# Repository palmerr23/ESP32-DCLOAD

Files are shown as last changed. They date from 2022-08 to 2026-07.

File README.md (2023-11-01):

# ESP32-DCload
An ESP32-based WiFi controlled DC load

## V3a code is development - not fully tested. Contains battery test, screen rotation and Kelvin sensing 'fix' code.

These files relate to a project published in Silicon Chip magazine in October 2022.  https://www.siliconchip.com.au/ 

Key features:

•	150V and 30A maximum values within a 300W power envelope.

•	Constant voltage (CV) current (CC), power (CP) and resistance (CR)modes

•	Short-circuit, battery and solar cell testing

•	Step test modes (square, ramp and triangle) with variable rise/fall times

•	Data logging

•	Touchscreen control panel 

•	Power off settings memory

•	Remote control via WiFi browser interface

•	SCPI programmable over WiFi and isolated USB

•	Over-voltage, over-current and reverse voltage protection

•	Definition files for the open source SCPI TestController instrument control application (https://lygte-info.dk/project/TestControllerIntro%20UK.html). 

Only compiled code is provided for 2.8" and 3.5" TFT screens (ILI9341 and ILI9488 controllers) as the number of libraries and complexity of code would make it difficult for others to get a clean compile.

The laser templates are designed for a 270mm x 210mm x 140mm blue metal enclosureavailable from eBay, Banggood and AliExpress. The templates have been tested with LightBurn, but should work with other laser cutter software.

The front panel was cut from 2mm acrylic, and the support panel for the CPU coolers from 3mm acrylic. 

The front panel was in the prototype was laser etched with the markings and the holes laser cut. The back of the panel was sprayed matt black. White wood filler was squeegeed into the etched labels and then polished off with very fine DRY sandpaper (> 600 grit). A final coat of clear spray was then appled to seal the wood filler and restore a gloss finish to the acrylic.

Alternately a white markings on black laser print could be mounted behind the clear acrylic panel.

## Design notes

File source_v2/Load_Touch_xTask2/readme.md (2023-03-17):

Additional libraries required:
* Adafruit GFX 
* ArduinoJSON (Benoit BLANCHON)
* ESP32 Wifi (I think all the necessary files are in the basic ESP32 package)
* ESPAsyncWebServer (https://github.com/me-no-dev/ESPAsyncWebServer)

Zip or folders for these have been included. Later versions may also work.
* ESP32 Encoder 
* ESP Rotary
* Button2

Compile with 
* "ESP32 Dev Module"
* Use one of the Partition Schemes with SPIFFS file system and OTA enabled. Minimal SPIFFS (1.9MB APP with OTA/190KB SPIFFS) is recommended.
* Use "Arduino Runs On Core 0" and "Events Run On Core 1". Running both on the same CPU results in lost ADS ADC interrupts.

Known to work with ESP32-WROOM DOWD2. Should work with WROVER as GPIO 16/17 are not required.

Do not use ESP32-S3 DevkitCs as the GPIO to pin number allocations differ.

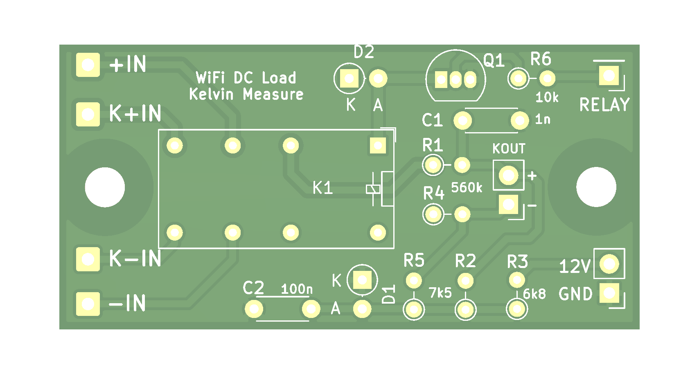
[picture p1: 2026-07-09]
Kelvin board image.png

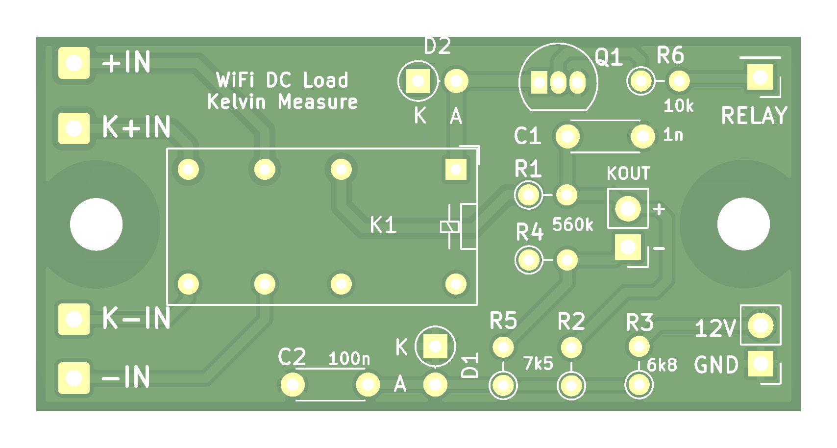
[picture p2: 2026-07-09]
Kelvin-gerber/Kelvin board image.png

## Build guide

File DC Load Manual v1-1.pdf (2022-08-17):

V1.1 – May 2022 | Programmable DC Electronic Load Manual | 1

# WiFi Programmable DC Load Manual

## V1.1 May 2022

This manual describes the features of WiFi Programmable DC Load. It should be read in conjunction with the LCD Controller manual, where some generic features and specifications of the control interface are documented.

## Key Features

- 150V and 30A maximum values within a 300W power envelope.
- Constant voltage (CV) current (CC), power (CP) and resistance (CR)modes
- Short-circuit, battery and solar cell testing
- Step test modes (square, ramp and triangle) with variable rise/fall times
- 10 mA and 10 mV resolution
- Touchscreen Control
- Data logging
- Browser and SCPI programmable over WiFi
- Remembers last five WiFi connections
- Power off settings memory
- Temperature controlled fans
- Over-voltage, over-current and reverse voltage protection
- Modular design allows expansion to higher current loads. Repository: https://github.com/palmerr23/ESP32-DCLOAD

© 2022 Richard Palmer

## Contents

## Safety

Isolated remote control and monitoring via WiFi is the recommended approach for this instrument.
1. Once commissioned, do not make a non-isolated USB connection to the instrument.
- Almost certain damage will occur if the + terminal is connected to GND and a non-isolated USB connection is also made. This connection would create a ground loop of the full output voltage of the supply, as the ESP32’s USB ground is hard wired to the – terminal of the supply.
- Differing ground potentials may also cause damage if the – terminal is connected to GND terminal unless a USB isolator is employed where a mains earth differential is present between the computer and the supply. Both the computer and instrument may be damaged in either case.
2. The load and DUT are NOT PROTECTED under some conditions.
- The load is capable of sinking far in excess (> 100A) of its rated current under some conditions.
- A relay provides some protection for the DUT, but the pulse current may be substantial until this happens.
- The load will sink substantial current if reverse voltage is applied.
While the load is voltage and current protected (relay protected),
the DUT may be damaged by transient currents.
- The load is protected by relay disconnection beyond its maximum input voltage (150V). However, damage may still occur if voltages above this value are applied.
3. The rated voltages and currents of this load are capable of substantial damage, injury or death.
- Never operate the load with the cover removed.
- Ensure that safe work practices are used when the load is used to test high voltages and/or currents.
- Ensure that the load’s current setting is always less than the DUT’s safe maximum
- Undertake DUT short circuit testing with the load’s maximum current setting only a small amount above the DUT short circuit design value.

## Overview

The WiFi Programmable Electronic DC Load offers high performance and flexibility. It has a user-friendly interface, and solid performance specifications, while being withing the capability of the advanced electronics amateur to construct. Its modular construction allows the constructor to select the most appropriate enclosure and panel layouts for their purposes.

Main features:

- Single channel, DC 150V/30A, total power to 300W
- 4 static modes: CV (Constant Voltage), CC (Constant Current), CP (Constant Power) or CR (Constant Resistance) .
- Dynamic (step) mode offering square, triangle and sawtooth operation in CC, CR, CP or CR modes
- Battery characterisation and testing functions
- 3.5” touch TFT, providing a flexible control interface for all settings and readings.
- Kelvin (4-wire) sensing of Device Under Test voltage.
- Built-in WiFi control via SCPI or Web interface.
- Power-off memory function

## Front Panel

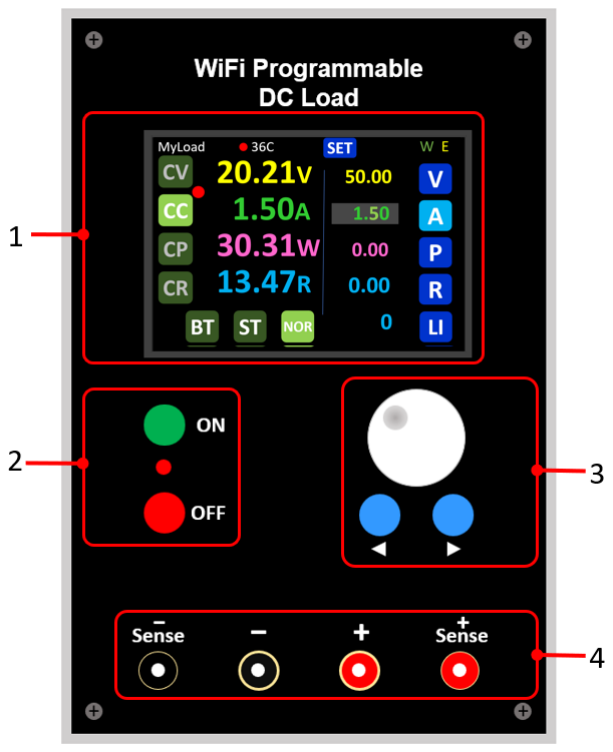
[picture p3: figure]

1. TFT touch control screen
2. On/Off buttons and LED indicator
3. Numeric setting controls
4. Binding posts and Kelvin sensing terminals.

## Operating Modes

## Constant Current (CC)

The electronic load will attempt to sink a current in equal to the set value regardless of the input voltage.

## Constant Voltage (CV)

The load will attempt to sink enough current to control the input voltage to the set value.

The load acts as a shunt voltage regulator when operating in CV mode.

## Constant Power (CP)

The load will attempt to sink constant power in CP mode.

The load current will change linearly proportional to the input voltage to keep sinking a constant power (P = V x I).

## Constant Resistance (CR)

The load attempts to behave like a constant resistance, and changes the current linearly proportional to the input voltage.

## Special Functions

Instructions for using the special function modes are provided in the General Operation section.

## Battery Test (BAT)

The Battery Test function discharges a battery at a known rate until it reaches a defined voltage. At that point the load switches off.

During this process two characteristics are measured:

- | Capacity | Discharge from fully charged to end voltage. Sum the power delivered over time.
- Internal Resistance
| (Equivalent Series Resistance) | Compare the open circuit voltage to the voltage under discharge at a known current.

The characteristics of some common battery types, and appropriate testing values, can be found at the end of this document.

## Step Mode (STEP)

In Step mode, the load can be programmed to switch between two setpoints, or to generate sawtooth or triangular staircases.

The rise and fall time for the steps is also programmable.

## Safe Operating Area and Protection

The device will limit voltage and current in all operational modes and special functions so that it doesn’t operate beyond its maximum voltage, current and power ratings.

When the load is on Off mode, the relay is disengaged. However, the voltage sensing circuitry is still connected in Off mode.

The SOA limiting indicator (1) lights when SOA limiting is in effect.

## Safe Operating Area Protection

The load automatically limits its current when either the maximum power or current is exceeded.

If the applied voltage goes more than a few volts over the allowed maximum, the load will disconnect.

Limiting values are provided in the Specifications table at the end of this document.

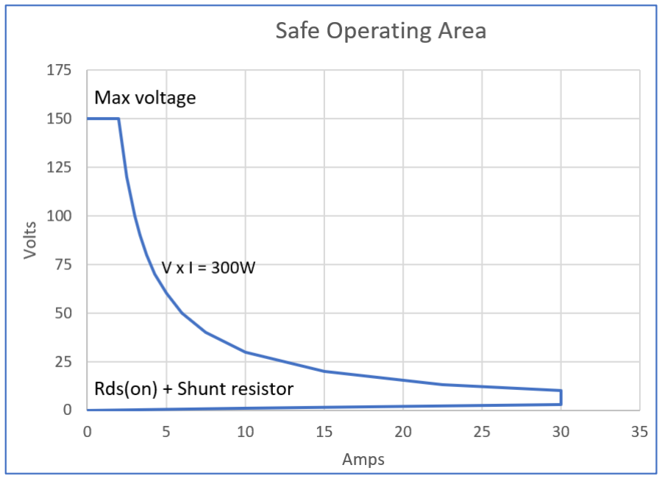
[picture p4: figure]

RDS(on) Limits

- The load has a finite minimum resistance which is a combination of the RDS(on) value of the MOSFETs and the current shunt resistors. The value of the combined minimum resistance is in the Specifications table at the end of this document.

Maximum Power

- The load will reduce the current if the applied voltage and actual load current exceed the maximum power dissipation (P = V * I).
- The SOA limiting indicator will light when this condition occurs.

Overvoltage Protection

- The load will set its target current to zero and disconnect, if a voltage greater than the maximum operating voltage is detected.
When the load is “disconnected” no current will flow, however voltage sensing is still in place.
- While the absolute maximum voltage is well-above the maximum operating voltage, damage will occur to the load if excessive voltage is applied.
- Maximum power limits also apply.

Maximum Current

- It is not possible to set the desired load current greater than the maximum operating value.
- The load will not allow the current to rise above the set value.
- Maximum power limits also apply.

## Reverse Voltage and Current

- The load DOES NOT control current in the reverse direction. If a DUT is connected in a way that provides a reverse voltage, substantially unlimited current will flow until the relay disconnects.
- It is unlikely that the load will be damaged by moderate reverse voltages and currents, however the DUT may be damaged if its current limit is exceeded.

## General Operation

This section describes the basic control functions and front panel operation.

There are some differences when using the web interface, which are described in the Remote Control section.

## On/Off Buttons

The buttons [5] below the LCD screen connect and disconnect the load from the Device Under Test (DUT).

When the load it is disconnected from the DUT, other than the voltage measuring circuit.

The LED [6] between the On and Off buttons indicates the current state of the load, which may also be controlled remotely.

## Screens and Menus

Menu items are selected using the coloured buttons on the touch screen [1, 2, 7 & 8]

For instance, on the main screen there are five buttons V, A, P, R & LI on the right-hand side, which set specific operational values. The buttons change brightness when selected to indicate their status (see Main screen settings, below).

On the left of the screen are buttons to select the main operating modes: CV (Constant Voltage), CC (Constant Current), CP (Constant Power) or CR (Constant Resistance).

Three special function menu buttons BT (Battery Test), ST (Step mode) and NOR (NORmal mode) are arranged across the bottom of the screen.

The SET (SETtings) button, at the centre top of the screen accesses sub-menus to control STep mode, COMmunication parameters, and CALibration functions.

Changing numeric values
Select the item with its associated on-screen button, and use the numeric setting controls [3 & 4] (rotary encoder and buttons) to alter settings. When a setting is selected its background is highlighted, as is one of the digits. The rotary encoder [3] will change the value by 1 unit of the highlighted digit per click. Clockwise rotation increases the value, anti-clockwise decreases it.

Voltage (V) setting selected and the ‘units’ digit being edited.

The highlighted digit is changed by the buttons [4] under the encoder (digit buttons). The left button will move the highlight to a more significant digit, and the right button to a less significant digit.

On/off settings
Touching a selection button for toggle controls [7] (BT, STEP and NOR) will change the value, as will rotating the encoder knob [3] or pressing the numeric setting buttons [4] (right button or clockwise rotation = On, left button or anti-clockwise rotation = Off).

Changing text values
An on-screen keyboard is displayed for test values when the associated selection button is touched. As the individual characters are small, a stylus is recommended to operate the on-screen keyboard.

When a character is touched, it is appended to the end of the string. Backspace deletes the last
character typed.

Shift buttons at the lower right and left change the

case off alphabetic characters and which symbols or numbers are displayed.

The Enter button saves the value and returns to the menu screen.

Processing of the underpinning menu screen is suspended while the on-screen keyboard is active.

## Main Screen

1. Indicators and settings menu button
2. Setting selection buttons
3. Voltage, Current, Power and Resistance value settings
4. Special function buttons
5. Operating mode selection buttons
6. Voltage, Current, Power and Resistance readings

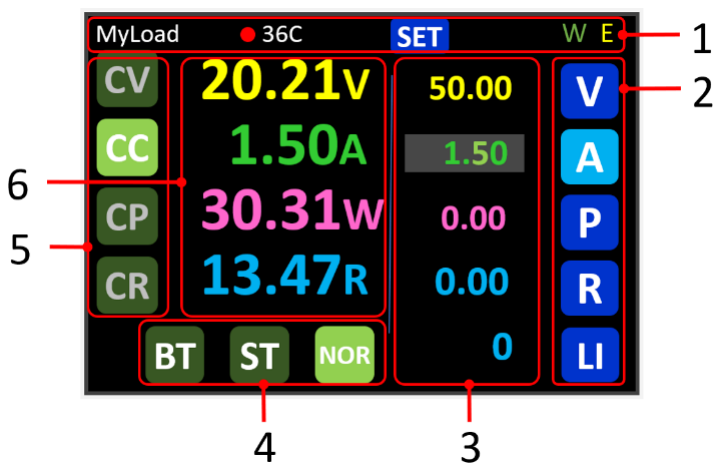
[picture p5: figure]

When values are out of range, the touch screen displays “***”. This most commonly occurs only for the calculated resistance reading, if the calculated value is > 999.99 Ohms
(high voltage and low current).

Top row of screen

- The name assigned to the device is on the left. It can be altered in the Settings > Communications menu.
- Heatsink temperature and fan indicator (no indicator = low speed, green = medium speed, red = full speed).
- The SET button provides access to the STEP, CAL and COM menus.
- Wireless connected (W) and EEPROM save pending (E) indicators on the right.

Main screen settings
Settings are saved automatically to EEPROM approximately thirty seconds after the last value was changed. The [E] indicator is displayed when a save is pending.

Values are not saved more regularly as EEPROM has a limited (~10,000) write cycle lifetime.

Voltage, current, power and resistance target setting
Touch the V, A P or R button on the screen to enable the related control setting.

Use the rotary encoder and buttons, as described in General Operation above, to set the desired output voltage.

Note: The screen settings display updates in real time if values are changed remotely (SCPI or web interface).

Mode setting
Touch the CV (Constant Voltage), CC (Constant Current), CP (Constant Power) or CR (Constant Resistance) buttons to select the desired operating mode.

When switched On, the load will seek an operating point corresponding to the related V, A, P or R setting.

Special Functions
The BT (Battery Test) and ST (STep mode) buttons at the bottom of the screen select these functions.

Pressing a special function button starts the function sequence. The button is red while the function is operating.

When the special function is operating, it can be aborted by touching the NOR button, or by pressing the Off switch on the main control panel.

## Setting the Operating Modes

## Constant Current (CC)

In CC mode, the electronic load will attempt to sink a current in equal to set value regardless of the input voltage.

The load will limit the current to within its Safe Operating Area (SOA) while in this mode.

Operation
1. Set the mode to CC and the desired current in Amps.
2. Connect the DUT and press the On button.
3. Pressing the Off switch will disconnect the load from the DUT.

Short Circuit Testing
Set the target current greater that the DUT’s maximum to test its short circuit capability.

Warning: The DUT may be damaged if the maximum current value is set too high.

## Constant Voltage (CV)

In CV mode, the load will attempt to sink enough current to control the input voltage to the set value. The load acts as a shunt voltage regulator when operating in CV mode.

The load will not sink more than the set current while attempting to reach
the desired voltage.

The load will limit the current to within its Safe Operating Area (SOA) while in this mode.

Operation
1. Set the mode to CV and the desired target voltage.
2. Set the maximum current.
3. Connect the DUT and press the On button.
4. Pressing the Off switch will disconnect the load from the DUT.

## Constant Power (CP)

The load attempts to sink constant power in CP mode.

The load current will change linearly proportional to the input voltage to keep sinking a constant power (P = V x I).

The load will not sink more than the set current while attempting to reach the desired power.

The load will limit the current and voltage to within its Safe Operating Area (SOA) while in this mode.

Operation
1. Set the mode to CP and the desired target power.
2. Set the maximum current.
3. Connect the DUT and press the On button.

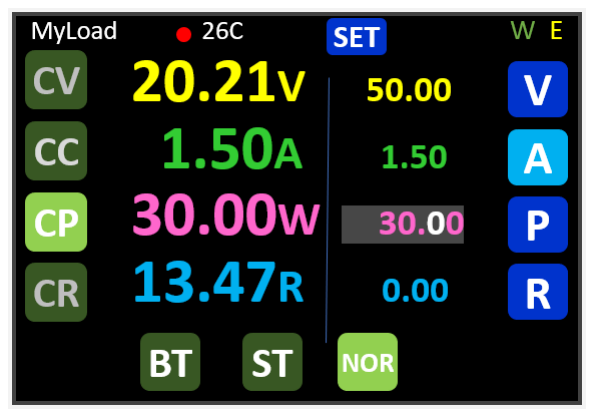
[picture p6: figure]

4. Pressing the Off switch will disconnect the load from the DUT.

## Constant Resistance (CR)

In CR mode, the load behaves like a constant resistance, and changes the current proportional to the input voltage.

The load will not sink more than the set current while attempting to reach the desired resistance.

The load will limit the current and voltage to within its Safe Operating Area (SOA) while in this mode.

Operation
1. Set the mode to CR and the desired load resistance.
2. Set the maximum current.
3. Connect the DUT and press the On button.

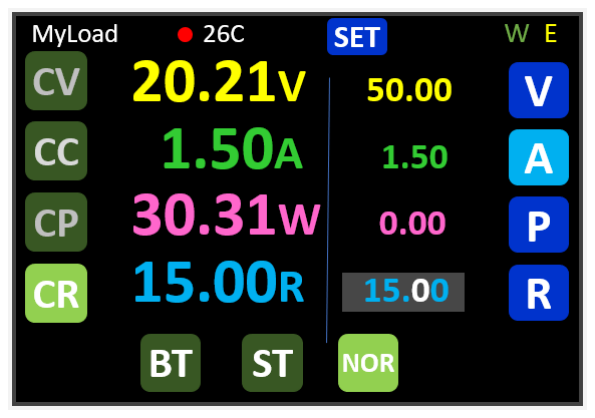
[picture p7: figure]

4. Pressing the Off switch will disconnect the load from the DUT.

## Step Mode

The Step function alternates between two setpoints and may operate in CC, CV, CR or CP mode.

It can provide a simple ‘square’ wave, alternating between the two setpoints; sawtooth or triangular staircases with a selectable number of steps.

The main screen V, A, P and R settings are disabled for Step mode, which has its own settings screen, accessed by touching the SET button on the main screen and then the STEP button on the SETTINGS menu.

1. First stage settings
a. Voltage
b. Current
c. Dwell time for each step
d. Number of steps in the staircase (0 = square or triangle wave)
2. Second stage settings (as for first stage)
3. Number of cycles of the S1/S1 sequence
4. Rise/Fall time between steps

Settings

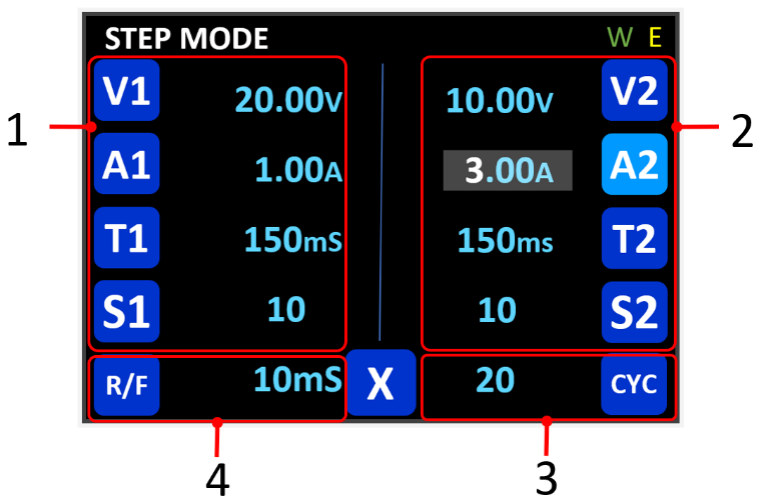
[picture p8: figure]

The operating mode (CC, CV, CR or CP) is selected on the main screen. The mode is combined with the parameters on the STEP settings screen to determine the appropriate operating point at any given moment.

S1 and S2 parameters:

- V&A: The desired voltage (CV mode) or current (CC mode).
For CR and CP modes, the desired value is calculated from P = V * A or R = V / A.
Any parameter for S1 may have a higher or lower value than that of S2.
- T: The time (mS)to dwell at each step of the staircase (triangle/sawtooth) or the time at each setting (square).
The minimum value of T is 5mS, to avoid rapid oscillation between the setpoints.
The dwell time includes any rise/fall time value.
- S: The number of steps between the two setpoints.
Setting both these value to 0 provides a ‘square’ wave, one zero generates a one-way staircase (sawtooth), both non-zero gives an up/down staircase (triangle) output.
CYCles: The number of iterations of the S1 / S2 sequence. Setting the value to zero causes endless repetition.

R/F: Rise and fall time (mS) between stages and steps.
The rise/fall slope is a series of 1mS steps between the two values, rather than a smooth transition.
Setting this value to zero will reduce the rise/fall times to the load’s minimum values (approx. 100uS).
The setting must be less than the dwell times (T1 and T2) for the slewing process to properly complete within each step or stage.

Note: for short rise/fall times(<100mS), particularly when the T1 or T2 parameters are also short (< 100mS), a distorted waveform may be generated, due to the ESP32 task scheduler needing to refresh the screen at regular intervals.

Operation
Step mode limits both current and voltage to the maximum for each step. Main screen modes and values are ignored while stepping.
- For voltage stepping mode operation, set A1 and A2 higher than required for the DUT.
- For current stepping mode, set V1 & V2 higher than the DUT will supply.
- Power and resistance stepping can be accommodated between two specific operating points defined by V1 & A1 and V2 & A2.

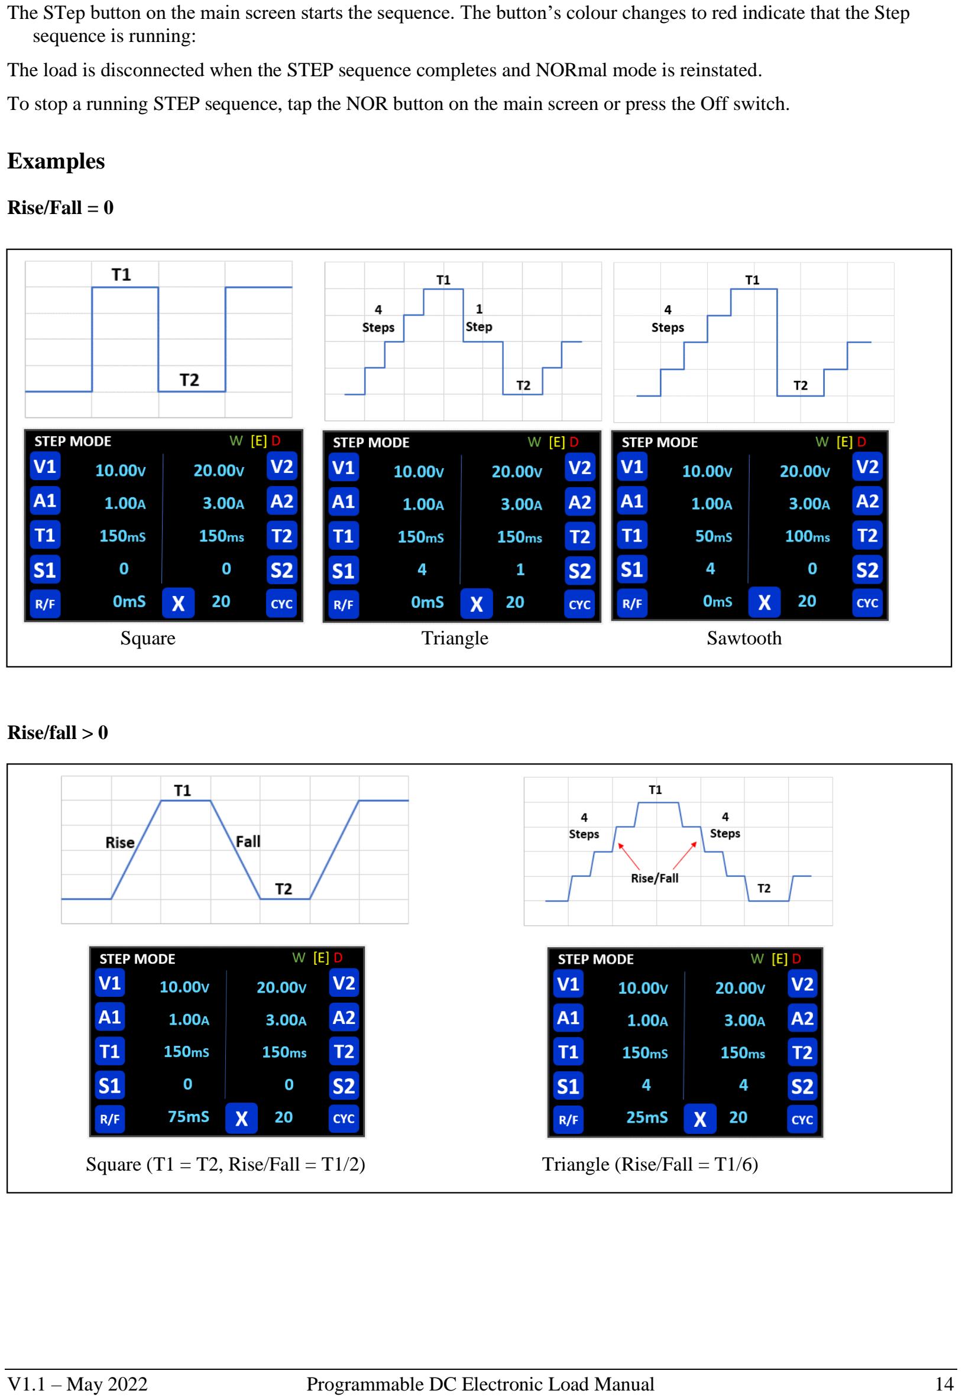
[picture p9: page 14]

The STep button on the main screen starts the sequence. The button’s colour changes to red indicate that the Step sequence is running:

The load is disconnected when the STEP sequence completes and NORmal mode is reinstated.

To stop a running STEP sequence, tap the NOR button on the main screen or press the Off switch.

Examples

Rise/Fall = 0

Rise/fall > 0

Square | Triangle | Sawtooth
Square (T1 = T2, Rise/Fall = T1/2) | Triangle (Rise/Fall = T1/6)

## Battery Testing Mode

While batteries are normally tested in Constant Current mode, CP mode can also be used.

CV mode is not available for battery testing. If it is selected at the start of a test, the mode will automatically switch to Constant Current mode, and the load will change to the Off state.

Settings
1. Battery test final (end of test) voltage
2. Discharge current or power
3. Battery test start button (BT)
4. Battery test cancel button (NOR)
5. Discharge modes (CC, CP or CR only)
6. Live readings
In battery testing mode Logging is always enabled, and a log item is stored every 60 seconds when the internal resistance is measured.

Operation

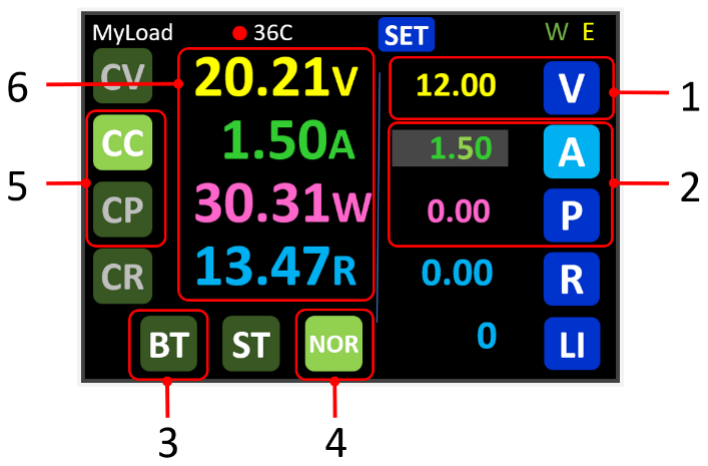
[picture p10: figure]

1. Touch the V button and enter the discharged battery voltage (endpoint for the test).
2. Select the appropriate discharge mode (CC, CR or CP) and enter the desired discharge rate (Amps, Ohms or Power) on the right hand settings.
3. Ensure the output is Off.
4. Connect the battery.
5. Touch the BAT button to initiate testing. The test will continue until the battery voltage reaches the set target voltage.
If the test immediately completes, try starting the test with the load connected (On).
6. During testing, the load will calculate the internal resistance of the battery at the beginning and end of the cycle and every 60 seconds during discharge. The discharge current is set to zero for a few seconds each time, so that the open circuit voltage can be measured.
The battery voltage, current and power being delivered are displayed on the screen while testing proceeds.
7. The test can be aborted at any time by touching the NOR button.
If the Off switch is used to cancel the test, the final values will not be displayed or logged.
8. Once the battery reaches the target discharge voltage, the load will change to the Off state and display the final test results – initial and final internal resistance and battery capacity (AH and mAH).

To stop a running battery test, tap the NOR button on the main screen. The test results, calculated to that point, will be displayed.

The Off switch will also cancel a test, however the final results are not displayed or logged.

At any time, until another test is started, or the load is switched to On, the test logs can be accessed via the web interface (see below).

The ESR and total energy (Watt-hours) discharged values are interleaved with the logged battery voltage readings, as they are calculated.

## Logging

Logging is managed via the main screen Log Interval (LI) setting. The minimum time between log entries is 10mS, and the minimum increment is 10 mS.

A zero (0) value in LI sets logging:

- disabled for NOR mode.
- to SYNC mode for STEP and BAT (see below).
Log values are available via the web interface, and may be queried at any point via SCPI.

The web interface does not need to be live throughout the duration of logging.

Logging results can be called up at any time during the test process or afterward. As the data is held in RAM memory, it is cleared when the load is switched On or the next BAT or STEP operation commenced.

If the maximum number of log measurements (1000) is reached, the earliest values logged are overwritten with newer data.

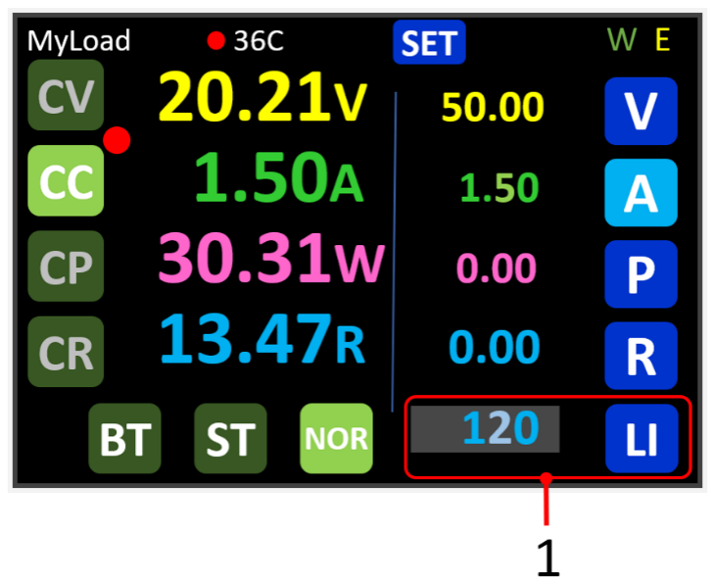
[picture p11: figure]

Operation
1. On the main screen set the LI parameter.
Very small values of Log Interval (<100mS) are not permitted to avoid high processor loads
A zero setting disables logging.
2. Logging data is cleared and logging re-started when any of the following occurs.
- The On button is pressed.
- BT or ST modes are initiated.
3. Log data stops being collected when the output is set Off, either by pressing the Off button, or STEP or BAT mode terminating.
Log data remains available, via the web or SCPI interfaces, until the On button is pressed, or another BAT/STEP cycle is initiated.

The log data format is detailed below.

Step Mode
In step mode, logging begins when Step mode is initiated and ceases when Step mode completes or is aborted.
SYNC mode (LT = 0) | Synchronises log reading with steps and stages. Takes one reading at the end of each step or stage.
FREE mode (LT > 0) | Free-running, logs at fixed intervals, regardless of Step mode settings. Logs each LT period, regardless of step and stage state.

Battery Test Mode
In BT mode, logging begins when BT mode is initiated and ceases when the test completes or is aborted.

Every 60 seconds, discharge is paused and the open circuit voltage measured, so that the battery’s internal resistance can be calculated. The open circuit voltage (OCV) and internal resistance (ESR) are logged.

SYNC mode (LT = 0) | Synchronises log reading with the regular calculation of battery internal resistance. Takes one reading at the end of each step or stage.
FREE mode (LT > 0) | Free-running, logs at fixed intervals, regardless of Step mode settings. Logs each LT period, regardless of step and stage state.

Note: In Battery test mode, the Setting line on the web interface plot includes the setting (CC, CR or CP value), the ESR and Open Circuit Voltage. The CSV log properly identifies all the different values of Setting.

Log Results
Results are available via the web interface or SCPI until the next cycle is initiated (On, BT or ST buttons pressed).

Partial results can be obtained at any point in the logging cycle by pressing the Update button on the Log tab of the web interface. Note that accessing large log datasets during a measurement sequence may cause delays to that sequence.

The data is presented as comma delimited text
(CSV) with a five line heading block and
column headers on row 6.

For each measurement, logging reports:

- Time of measurement is in milliseconds since the start of the test.
- Current reading (A)
- Voltage reading (V)
- Setting (V, A, W, R – as indicated by mode)
- Mode [CV, CC, CP, CR]
- Function [NOR, BAT, STEP]

Battery Test Logs
In Battery test mode, the Setting line on the web interface plot includes the setting (CC, CR or CP value), the ESR and Open Circuit Voltage. The CSV log properly identifies all the different values of Setting.
- Time of measurement is in seconds since the start of
the test.
- At the start of the test, after the load is connected
(On), the battery-is-discharged voltage setting and the discharge current or power setting are logged, depending on the discharge mode selected
- Every 60 seconds, and at the end of the test, the following data is recorded
- Equivalent series resistance (ESR_
- Open circuit voltage (OCV)
- Capacity in AH and mAH (CAP & CAPM)
- The values at the end of the run are recorded after the load has been disconnected.

DC Load Log

Project:

Date:

Operator:

Entries, 26

Time,Voltage,Current,Setting,Mode, Function

0,10.07,0.20,7.00,TERM_V,BAT

0,10.07,0.20,0.20,DIS_A,BAT

62,10.07,0.20,0.20,CC,BAT

63,10.07,0.20,10.58,ESR,BAT

63,10.07,0.20,12.23,OCV,BAT

63,10.07,0.20,0.00,CAP,BAT

63,10.07,0.20,3.42,CAPM,BAT

NOR button pressed or
terminal voltage reached.

70,12.23,0.00,10.52,ESR,BAT

70,12.23,0.00,10.14,CCV,BAT

70,12.23,0.00,0.01,CAP,BAT

70,12.23,0.00,9.33,CAPM,BAT

DC Load Log

Project:

Date:

Operator:

Entries, 3

Time,Voltage,Current,Setting,Mode,Function

0, 12.23, 0.25, 0.25, CC, NOR

50, 10.23, 0.25, 0.25, CC, NOR

100, 12.02, 0.25, 0.25, CC, NOR

Log Data Plot
The Log screen has a plotting function so that the progress of a test can be monitored.

There are two display options:

- The entire log
- The last 10 readings.

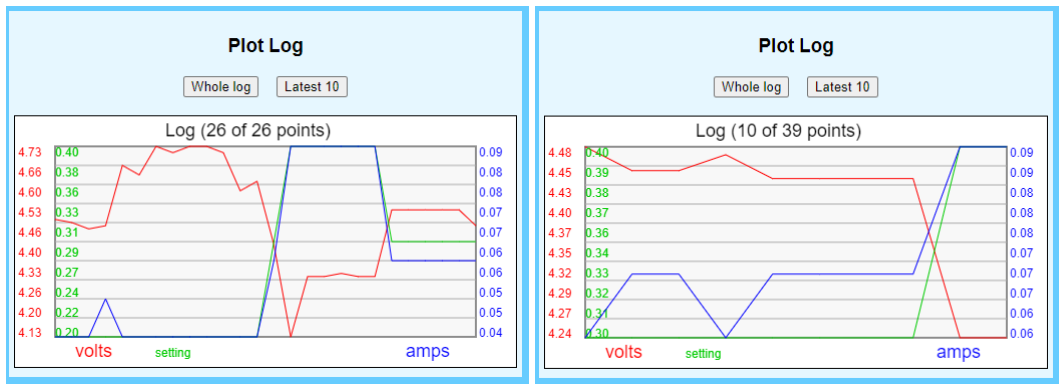
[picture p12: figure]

## Settings Menu

- The Settings menu provides access to three sub-menus:
- STEP: controlling the STEP mode settings
- CAL: voltage, current and screen calibration.
- COM: WiFi and hostname.
Note: Settings are not saved permanently until the [E] indicator at the top right of the screen has gone out (approx. 30 seconds after the last change).

## Step Screen

The operation of this menu is described in the General Operation section, above.

## Calibration Screen

The Calibration screen provides two functions

- Calibrating voltage, current and temperature measurements
- Aligning the touch screen (sub menu)

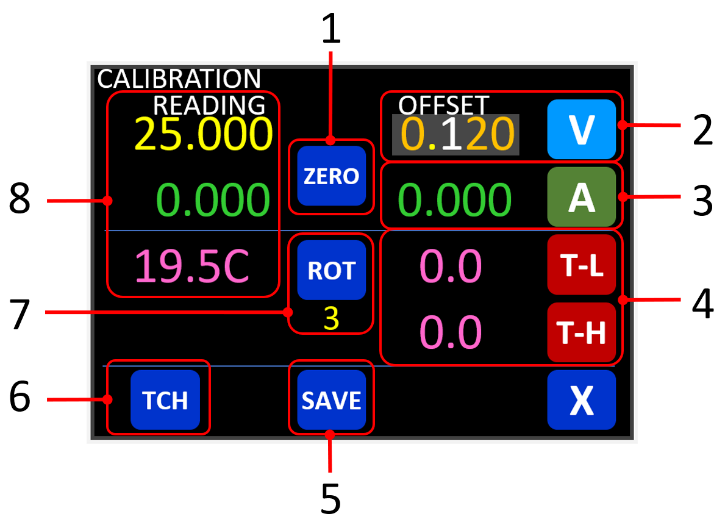
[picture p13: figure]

Voltage, Current and Temperature Calibration

Calibration Screen
1 | Zero current and voltage calibration button
2 | Voltage offset (calibration) button and value
3 | Current offset (calibration) button and value
4 | Temperature low and high offset buttons and values
5 | Voltage, current and temperature calibration update (Save) button
6 | Touch panel calibration menu button
7 | Touch screen rotate button and value
8 | Live voltage, current and temperature readings

High Volts Calibration
1. Connect the Load to a voltage source (preferably higher than 50V DC).
2. Connect a voltmeter across the load.
3. Do not press the load’s On switch.
4. Select CV and set the voltage to a higher value than the test voltage.
5. Navigate to the Calibration menu (SET > CAL).
6. Select the V button and set the voltage OFFSET value to the difference between the voltmeter reading and the value displayed on the left of the screen. If the displayed value is low, the required offset will be positive.
7. Press SAVE.
8. The offset is limited to +/- 5 V to avoid mishaps. If the error is beyond this limit, repeat the process until the correct value is reached.

High Amps Calibration
1. Connect the Load to a current source (preferably higher than 10A).
2. Connect an ammeter in series with the load.
3. Select CC and set the load’s current to the desired test current.
4. Press the load’s On switch.

5. Navigate to the Calibration menu (SET > CAL).
6. Select the A button and set the current OFFSET value to the difference between the ammeter reading and the value displayed on the left of the screen. If the displayed value is low, the required offset will be positive.
7. Press SAVE.
8. The offset is limited to +/- 2 A to avoid mishaps. If the error is beyond this limit, repeat the process until the correct value is reached.

Zero Volts and Amps Calibration
1. Disconnect the Load from any source.
2. Navigate to the Calibration menu (SET > CAL).
3. Touch the ZERO button (the voltage and current zero offsets are automatically calculated).
4. Press SAVE
Zero amps calibration is automatically performed whenever the output is off for more than a few seconds.

Temperature Calibration
A two-point calibration process is used for temperature.
- The LOW value should be close to 20°C (room temperature).
- The HIGH value should be close to the shut-off temperature (65°C).
If a more convenient method is not available, equal volumes of room temperature (20°C) and boiling water will produce a temperature close enough to 60°C for our purposes.
1. Stabilise the thermistor at a suitable low temperature.
2. Input the offset into the T-L setting on the calibration menu.
3. Press SAVE.
4. Repeat the process with a suitable high temperature and the T-H button.

Each calibration setting may be saved separately, or several calibrations made while in the menu, then saved.

All calibration settings are be saved to EEPROM after the E indicator goes out (approx. 30 seconds after the last setting or calibration change).

Touch Screen Alignment

Screen Rotation
Some TFT displays have the touch panel rotated by 180 degrees. If your touch panel does not appear to be responding, tap the main screen diagonally opposite to the SET button. If the SETTINGS menu appears, tap the CAL button in the middle of the screen enter the CALIBRATION menu to rotate the touch settings.

The number under the ROT button will be 1 or 3 depending on the current touch panel rotation.

Touch screen alignment is only required if the
control buttons or on-screen keyboard touch positions are offset from the display.

Touching the screen six times on the + sign at the top left corner of the blue screen, and then 5 times on the + sign at the bottom right corner of the red screen calibrates the touch screen relative to the display panel.

A stylus is recommended for this operation.

## Communications Screen

1 | SSID button and value
2 | WiFi Passphrase button and value
3 | WiFi Auto-connect button
4 | Hostname (instrument name) button and value
5 | IP address reading
6 | Local hostname reading
The Communications screen is entered by touching the
COM button on the main screen, and exited with the X
button.

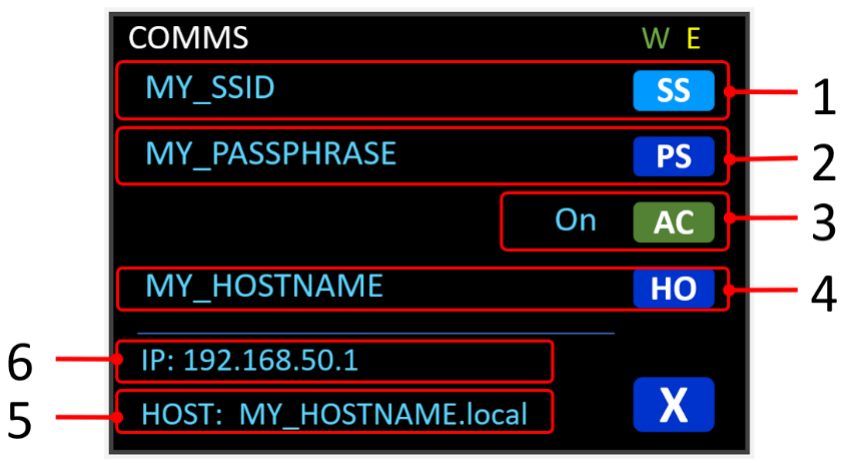
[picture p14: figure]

The load remembers the last five SSIDs entered, replacing the least-recently used if additional credentials are saved.

## Changing settings

Select the appropriate blue button to change the SSID or WiFi passphrase using the on-screen keyboard, as outlined above. Hostname changes will not affect the Web address (HOST:) until the WiFi connection is refreshed (AC Off then On).

To satisfy the requirements of IEEE 802.11 value and are case-sensitive.

- SSIDs may be up to 32 characters in length. While any valid 8-bit value (e.g. special characters) is permitted,
| non-alphabetic and non-numeric values should be used with care.
- Passphrases must be between 8 and 32 characters long (WPA2 enforces an eight character minimum). Any
| legitimate 8-bit value is acceptable.

Changes to Windows 10/11 Bonjour services in 2021 mean that the load can no longer be addressed as hostname.local without Windows registry changes.

## Remote Control

## Web Interface

A simple web interface is provided for the supply. It is accessible from the web address indicated on the COM screen, (on the standard Port 80). Using the example above, the URLs would be:

http://192.168.50.1
or
http:// MY_HOSTNAME.local (not available on some WiFi LANs / operating systems).

Accessing the web interface
The URL for the web screens is found on the SETTINGS > COMMS menu. Either the IP address can be used or the hostname*.

Communication is not encrypted.

* On some WiFi LANs the hostname mode
may not work due to router or operating
system configurations.

Main Tab
The main screen operates in a manner similar to the load’s front panel.

The main difference is that a Settings value [2] is clicked to enable editing.
The selected value has a white background (Watts in the diagram below).

The radio buttons [4] under the scrubber knob [3] determine which unit is changed [e.g. tens, units or decimals).
(Each unit of knob rotation will increment/decrement by one unit in the diagram below).

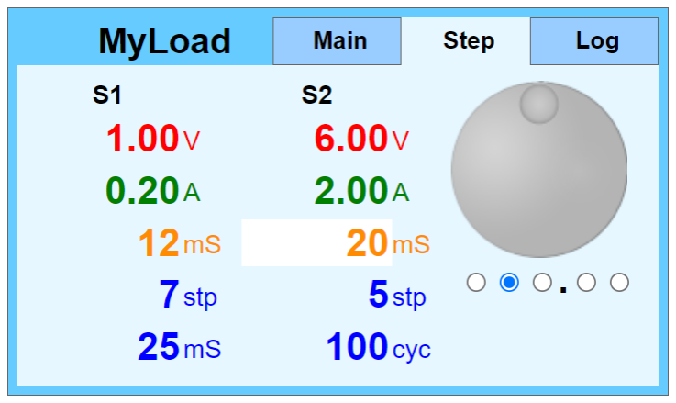
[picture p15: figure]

Step Tab
As for the Main menu, in the Step menu, the are selected for editing by clicking on the value.
(S2 dwell time is selected in the diagram below, and each unit of knob rotation will increment/decrement by ten units).

Log Tab
The Log tab has two functions:

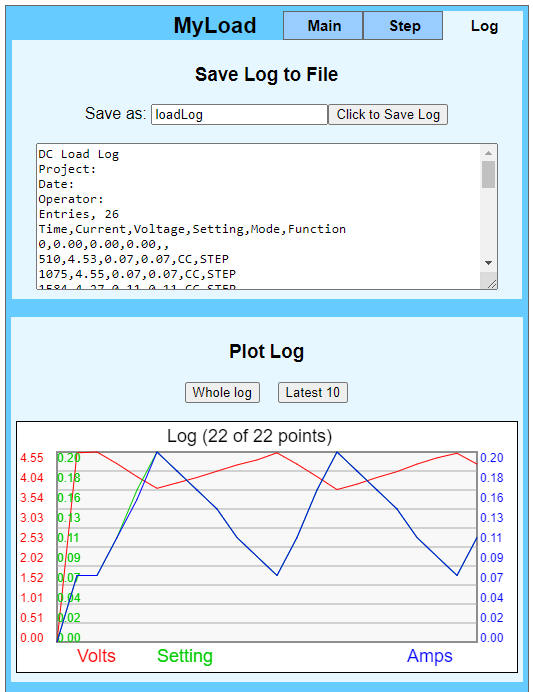
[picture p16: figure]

1. To save Log data to a host computer.
2. to graphically display the current log data, mainly to ensure it is being correctly captured during a test cycle.

Save Log data
1. Enter a file name into the Save as: field.
2. Click the Save Log button.

Data will then be copied into the text box as well as saved to the host computer.

The size of the text box can be altered by dragging the bottom corner of the right-hand
scroll bar

The plotting function auto-scales to the values displayed. The Setting value displayed is that indicated by the function mode (CV, CC, CR or CP).

In the diagram opposite the mode is CC (see log file listing) so the green Setting value plotted is Amps (almost identical to the blue Amps data).

## TestController

Most of the inbuilt functions are controllable from the device Setup in TestController. Calibration is not supported on any of the remote-control interfaces. TestController has its own logging and charting functions.

It is best to avoid changing settings on either the touch screen or the web interface while using TestController, as values are not always updated in TestController if they are changed elsewhere.

Extensive documentation is available at
https://lygte-info.dk/project/TestControllerCommands%20UK.html

The TestController forum is at https://www.eevblog.com/forum/testgear/program-that-can-log-from-many-multimeters/

Configuration
Copy the PlatyLoad.txt device definition file downloaded from the repository into the Devices folder at the location you installed the TestController program.

Copy the PlatyLoadHelp.txt file into you Documents > TestController > Settings folder. Once loaded, as you start to type commands, the Help window below the command line will display the remaining command options.

The setup screen and help information will be available next time TestController is started.

Add the device on the Load Device tab. If DHCP is being used, the DNS name of the device is a better way to identify its Address, as the device’s assigned IP address may change over time.

The Load Devices tab with several devices added. The DNS name for the device or its IP address can be used. Hostnames are not case-sensitive.

Operation
All of TestController’s main functions should operate once the device has been connected.

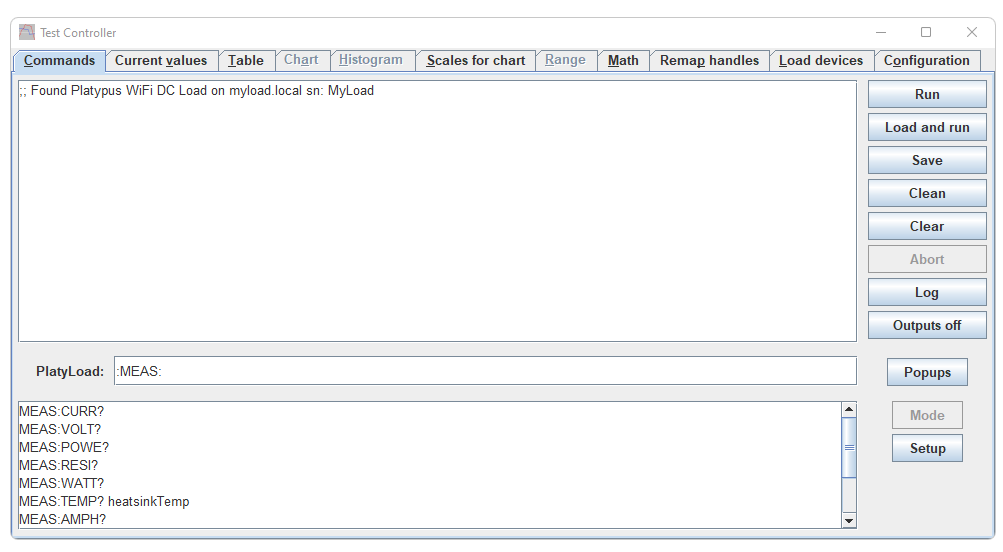
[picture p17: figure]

The main TestController window with the PlatyLoad device selected. There is a partially typed MEASure command in the command line, and the Help widow is displaying the remaining command options.

The Device Setup pop-up window
The Setup pop-up window is opened by clicking on the Setup button on the TestController Command tab, when the Load is selected (Command Line). Most Load settings can be managed from this pop-up, excluding logging and calibration.

The Load’s current settings are loaded into the pop-up when it is opened. They are not updated after that, unless a value is changed using the pop-up’s controls. Therefore, it is not advisable to change settings on either the touch screen or the web interface while using TestController, as the current settings may not be displayed in the pop-up window if they are changed elsewhere.

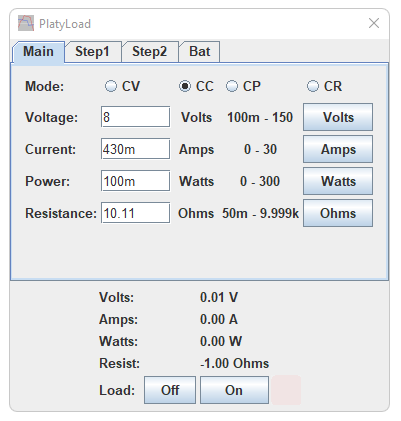
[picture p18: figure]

The Main device pop-up tab. Mode and control values are set in the top section and readings are displayed in the bottom panel.

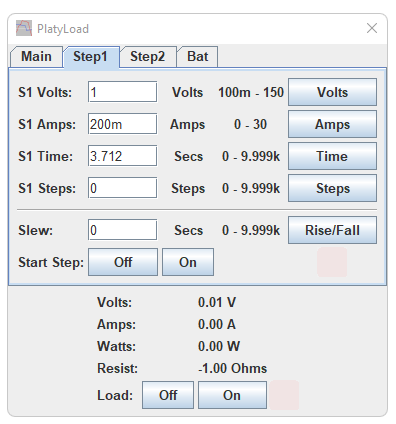
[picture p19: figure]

The Step function screens.

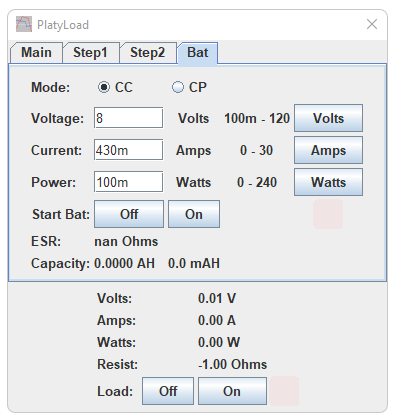
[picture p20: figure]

The Battery testing function screen

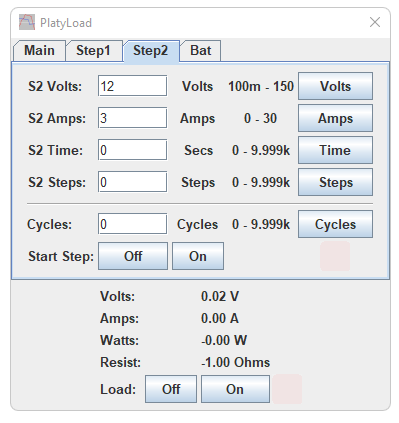
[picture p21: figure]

## SCPI Communication

Standard Commands for Programmable Instruments (SCPI) was developed in the early 1990’s to provide a common syntax and command structure for programmable instruments from power supplies to oscilloscopes and beyond. It was designed as a master-slave protocol, with the controlling software always being master. While it was originally implemented on the GPIB bus (IEEE 488) other protocols, such as serial (including USB serial) and Telnet, are now commonly used.

The IVI Foundation, which is the successor to the non-profit SCPI Consortium, has a website with exhaustive documentation on SCPI and more recently developed, and more flexible instrument communication protocols such as VISA and VXI. https://www.ivifoundation.org/specifications/default.aspx

SCPI commands can be processed from several sources:

- A TELNET connection on Port 5025, for instance from TestController.
- A command packet from a member of the same tracking group as this instrument via UDP packet on Port 8888. (Messages for other tracking groups are read and discarded).
While USB Serial terminal, such as the Arduino Serial Monitor can also be used, significant care needs to be taken to avoid ground loops. (See the safety warning at the beginning of this document). It is highly recommenced that an isolated USB serial connection be used to avoid damage to the computer or instrument. USB Serial commands are equivalent to Telnet.

SCPI Command Format
Commands consist of case-sensitive keywords, separated by colons, and each keyword may have parameters associated with it, e.g. “:SOURce:VOLTage 350 mV” or “:MEASure:VOLTage?”

Commands ending in a question mark are queries, and the instrument should return a value or set of values to any query.

Parameters may be integers, floating point numbers or strings, depending on the command. Numeric commands may be followed by a unit, such as V, mV, A or mA.

Each command, such as “MEASure” can be issued using the full form or by using an abbreviation, which is always the part in upper case, and almost always four characters long. Thus “:MEAS:VOLT?” is equivalent to “:MEASure:VOLTage?”

Some SCPI rules for this instrument:

- Commands are case sensitive. “ABCX” is not equivalent to “aBCX”
- There must be one or more spaces between a command and its argument.
- There may be one or more spaces between an argument and its unit specifier
- String arguments are not enclosed in quotes
- No other spaces are permitted within or between commands. For instance, “:INST:NAME Fred” (no extra spaces) is legal and “: INST : NAME Fred” (extra spaces) is illegal.
- All commands must start with a ‘*’ or a ‘:’, and colons must be inserted between each command in a command line.
- Where unit specifiers are omitted, the natural unit (e.g. Volts, Amps) will be assumed.
- Case is significant in unit specifiers, as the SCPI interpreter recognises a wide range of the possible SI prefixes, e.g. m [milli] and M [mega].
- Floating point number should always have a numeral before a decimal point (leading zero).
- Incorrectly formatted commands will be rejected, and an error message returned, eg.
SCPI_proc: unknown cmd [MY_BAD_CMD]
- Only one command may be issued on each command line.
- Floating point values are stored as single-precision. Thus, 7 significant figure accuracy is available, but not required.
Value are generally returned with four decimal places, however accuracy may be limited to less decimal places. See the instrument Specifications table for value limits and accuracy.
In the detailed explanation of commands below

- Square brackets [ ] indicate the type of input required, e.g. [floating point] or [command]
- Angle brackets < > indicate the specific options available, e.g. <ON|OFF> or <CH1|CH2

SCPI Argument and Return Value Types

Data type | Description
Value | Floating point number. A A leading zero is required for values < 1.0. Actual value set may be constrained by limits embedded in the instrument.
Unit | A one or two character SI value of Amps or Volts (only V, mV, A, mA are recognised).
ON/OFF | String containing the characters {ON | OFF}. Case sensitive.
Group | Integer [1 .. 255]. Group 0 is reserved.
String | Alpha numeric, plus keyboard symbols, no spaces (ASCII 0x21 .. 0x7E). No quote marks. Case sensitive.

## SCPI Command Quick Reference

Command tree | Argument | Function
*IDN? | | | | Identify instrument
*TST? | | | | Self-test (POST) results
:SOURCce
| :VOLTage | | <float[V]> | Set voltage
| :VOLTage? | | | Get set voltage
| :CURRent | | <float[A]> | Set current
| :CURRent?
| :POWEr | | <float[W]> | Set power
| :POWEr?
| :RESIstance | | <float[R]> | Set resistance
| :RESIstance?
| :LOGInterval | | <unsigned integer[S]> | Set log interval
| :LOGInterval?
| :STATe | | <ON|OFF> | output on/off
| :STATe?
:MEASure
| :VOLTage? | | | Measure actual voltage
| :CURRent? | | | Measure actual current
| :POWEr? | | | Measure calculated power
| :RESIstance? | | | Measure calculated resistance
| :TEMP? | | | Measure heatsink temperature
| :LOGData? | | | Current run log data (up to 1000 CSV entries)
:FUNCTION
| :BATTery
| | :STATe | <ON|OFF> | Start/stop Battery test
| | :STATe?
| | :ESR? | | Last calculated ESR value
| | :CAPAcity? | | Last calculated total power discharged
| :STEP
| | :STATe | <ON|OFF> | Start/stop Step mode
| | :STATe?
| | :ACURrent | <float[A]> | S1 current
| | :ACURrent?
| | :BCURrent | <float[A]> | S2 current
| | :BCURrent?
| | :AVOLtage | <float[V]> | S1 voltage
| | :AVOLtage?
| | :BVOLtage | <float[V]> | S2 voltage
| | :BVOLtage?
| | :ATIMe | <unsigned integer[S]> | S1 step time
| | :ATIMe?
| | :BTIMe | <unsigned integer[S]> | S2 step time
| | :BTIMe?
| | :ASTEps | <unsigned integer[S]> | S1 number of steps
| | :ASTEps?
| | :BSTEps | <unsigned integer> | S2 number of steps
| | :BSTEps?
| | :SLEW | <unsigned integer[S]> | Rise/fall time
| | :SLEW?
| | :CYCLes | <unsigned integer> | Number of cycles to repeat
| | :CYCLes?
:SYSTEM
| :ERROR?
| :PASSword | | <text> [8-63 chars] | WiFi password
| :PASSword?
| :SSID | | <text> [2-32 chars] | WiFi SSID
| :SSID?
| :CONNect | | <ON|OFF> | Auto connect to WiFi
| :CONNect?
| :HOSTname | | <text> [2-16 chars] | Network Hostname
| :HOSTname?

## SCPI Command List

*IDN?

Command format | *IDN?
Description | Identify the instrument
Return Info | Manufacturer, product type, instrument name/serial number, software version
Typical return | Platypus,DCL01,myLoad,2

MEASure

Command format | :MEASure:[parameter]?
Description | Query the actual value (reading)

CURRent?

Command format | :MEASure:CURRent?
Description | Measure load current
Return Info | Floating point (Amps)
Typical return | 3.00 (Zero if load is off)

VOLTage?

Command format | :MEASure:VOLTage?
Description | Measure voltage on the output binding posts, or 4-wire (Kelvin) terminals in
Return Info | Floating point (Volts)
Typical return | 12.00

POWEr?

Command format | :MEASure:POWEr?
Description | Return calculated power (volts * amps)
Return Info | Floating point (Watts)
Typical return | 28.5

RESIstance?

Command format | :MEASure: RESIstance?
Description | Return calculated load effective resistance (volts / amps).
Return Info | Floating point (Ohms)
Typical return | 28.5 (-1.00 if out of calculation range)

TEMPerature?

Command format | :MEASure:TEMPerature?
Description | Query the current heatsink temperature
Example | :SOUR:TEMP?
Return Info | Floating point, in degrees C

Typical return 28.5

WAVEdata?

Command format | :MEASure:WAVEdata?
Description | Return
Return Info | Complex, see section “WAVEdata”, below
Typical return | CSV formatted data

SOURce

Command format | :SOURce:[command]
Description | Set or query operational settings, such as voltage, current, or output status

MODE

Command format | :SOURce:MODE [command]
Description | Enable CV, CC, CP or CR mode
Example | :SOUR:MODE CC

MODE?

Command format | :SOURce:MODE?
Description | Query the current mode
Return Info | Text <CV|CC|CP|CR>
Typical return | CC

VOLTage

Command format | :SOURce:VOLTage [float] [unit]
Description | CV Mode: | Set the desired voltage for when the output is ON
BAT function: Set the Battery Test fully-discharged trigger voltage.
Example | Each of these commands will set the target voltage to 2.50V
:SOUR:VOLT 2.50V
:SOUR:VOLT 2500 mV
:SOUR:VOLT 2.50

VOLTage?

Command format | :SOURce:VOLTage?
Description | Query the current target voltage setting
Return Info | Floating point, in Volts.
Typical return | 12.00

CURRent

Command format | :SOURce:CURRent [float] [unit]
Description | All Modes and functions: Set the maximum current that the load will sink when On

Example | Each of these commands will set the target limit current to 2.50A :SOUR:CURR 2.50A :SOUR:CURR 2500 mA :SOUR:CURR 2.50

CURRent?

Command format | :SOURce:CURRent?
Description | Query the target current limit setting
Return Info | Floating point, in Amps
Typical return | 2.00

POWEr

Command format | :SOURce:POWEr [float] [unit]
Description | All Modes and functions: Set the maximum power that the load will sink when On
Example | Each of these commands will set the target limit current to 2.50 Watts :SOUR:POWE 2.50 W :SOUR:POWE 2500 mW :SOUR:POWE 2.50

POWEr?

Command format | :SOURce:POWEr?
Description | Query the target power limit setting
Return Info | Floating point, in Watts
Typical return | 2.00

RESIstance

Command format | :SOURce:RESIstance [float] [unit]
Description | CR mode: Set the target resistance for the load will sink when On
Example | Each of these commands will set the target resistance to 2.50 Ohms :SOUR:RESI 2.50 R :SOUR:RESI 2500 mR :SOUR:RESI 2.50

RESIstance?

Command format | :SOURce:RESIstance?
Description | Query the target resistance setting
Return Info | Floating point, in Ohms
Typical return | 2.00

LOGInterval

Command format | :SOURce:LOGInterval [float] [unit]
Description | Set the time between logged measurements
Example | Each of these commands will set the log interval to 2.50 Seconds :SOUR:LOGI 2.50 S :SOUR:LOGI 2500 mS :SOUR:LOGI 2.50

LOGInterval?

Command format | :SOURce:LOGInterval?
Description | Query the time between logged measurements setting
Return Info | Floating point, in Seconds
Typical return | 2.00

STATe

Command format | :SOURce:STATe <ON|OFF>
Description | Turn the output on or off
Example | :SOURce:STATe ON :SOURce:STATe OFF

STATe?

Command format | :SOURce: STATe?
Description | Query the current status of the output
Return Info | Text <ON|OFF>
Typical return | ON

FUNCtion

Command format | :FUNCtion:[command]
Description | Set or query Battery Test or Step Mode variables

BATTery

Command format | :FUNCtion:BATTery:[command]
Description | Set or query Battery Test variables

STATe

Command format | :FUNCtion:BATTery:STATe [command]
Description | Start or stop the Battery test function.
Example | :FUNCtion:BATTery:STATe ON

STATe?

Command format | :FUNCtion:BATTery:STATe?
Description | Returns Battery Test function status.
Typical return | ON

ESR?

Command format | :FUNCtion:BATTery:ESR?
Description | Return the latest ESR calculation
Return Info | Floating point, in Ohms
Typical return | 8.5

CAPAcity?

Command format | :FUNCtion:BATTery:CAPAcity?
Description | Return the latest battery capacity calculation
Return Info | Floating point, in Amp-Hours
Typical return | 1.5

STEP

Command format | :FUNCtion:STEP:[command]
Description | Set or query STEP mode variables

STATe

Command format | :FUNCtion:STEP:STATe [command]
Description | Start or stop the STEP mode function.
Example | :FUNCtion:STEP:STATe ON

STATe?

Command format | :FUNCtion:STEP:STATe?
Description | Returns STEP mode function status.
Typical return | ON

ACURrent or BCURrent

Command format | :FUNCtion:STEP:ACURrent [command] or :FUNCtion: STEP:BCURrent [command]
Description | STEP Mode: Set the S1 or S2 target current
Example | :FUNCtion:STEP:ACUR 5

ACURrent? or BCURrent?

Command format | :FUNCtion:STEP:ACURrent? or :FUNCtion:STEP:BCURrent?
Description | Returns STEP mode S1 or S2 target current setting (Amps).
Typical return | 4.8

AVOLtage or BVOLtage

Command format | :FUNCtion0 STEP:AVOLtage [command] or :FUNCtion: STEP:BVOLtage [command]
Description | STEP Mode: Set the S1 or S2 target voltage
Example | :FUNCtion:STEP:AVOLT 15

ACURrent? or BCURrent?

Command format | FUNCtion:STEP:AVOLtage? or :FUNCtion: STEP:BVOLtage?
Description | Returns STEP mode S1 or S2 target voltage setting (Volts).
Typical return | 12

ATIMe or BTIMe

Command format :FUNCtion:STEP:ATIMe [command] or :FUNCtion: STEP:BTIMe [command]

Description | STEP Mode: Set the S1 or S2 dwell time. (milliSeconds)
Example | :FUNCtion:STEP:ATIME 0.15

ATIMe? or BTIMe?

Command format | :FUNCtion:STEP:ATIMe [command] or :FUNCtion: STEP:BTIMe [command]
Description | Returns STEP mode S1 or S2 dwell time. (milliSeconds)
Typical return | 1.5

ASTEps or BSTEps

Command format | :FUNCtion:STEP:ASTEps [command] or :FUNCtion: STEP:BSTEps [command]
Description | STEP Mode: Set the number of steps for the S1 or S2 staircase.
Example | :FUNCtion:STEP:ATIME 3

ATIMe? or BTIMe?

Command format | :FUNCtion:STEP:ASTEps? or :FUNCtion: STEP:BSTEps?
Description | Returns the number of steps for the S1 or S2 staircase
Typical return | 3

ACYCles or BCYCles

Command format | :FUNCtion:STEP:ACYCles [command] or :FUNCtion: STEP:BCYCles [command]
Description | STEP Mode: Set the number of complete S1 / S2 cycles before Step mode exits.
Example | :FUNCtion:STEP:ATIME 3

ACYCles? or BCYCles?

Command format | :FUNCtion:STEP:ACYCles? or :FUNCtion: STEP:BCYCles?
Description | Returns the number of complete S1 / S2 cycles before Step mode exits
Typical return | 3

SLEW

Command format | :FUNCtion:STEP:SLEW [command]
Description | STEP Mode: Set the rise / fall time of each step. (milliSeconds)
Example | :FUNCtion:STEP: SLEW 0.015

SLEW?

Command format | :FUNCtion:STEP:SLEW?
Description | Returns the rise / fall time of each step. (milliSeconds)
Typical return | 1.5

SYSTem

Command format | :SYSTem:[command]
Description | Set or query system variables such as hostname and WiFi credentials

ERROR?

Command format | :SYSTem:ERROR?
Description | Return all the error messages currently queued and reset the queue.
Example | :SYST:ERROR?
Typical return | -200,"Command error; Invalid set voltage 3690.00"

SSID

Command format | :SYSTem:SSID [string]
Description | Set the SSID of a preferred WiFi LAN The SSID must be 8 – 32 characters in length to conform with the 802.11 specification.
Example | :SYST:SSID MyHomeWiFi

SSID?

Command format | :SYSTem:SSID?
Description | Returns the SSID of the connected WiFi LAN
Typical return | MyHomeWiFi

PASSphrase

Command format | :SYSTem:PASSphrase [string]
Description | Set the passphrase for the last entered SSID. The argument string is case sensitive. The passphrase must be 8 – 32 characters in length to conform with the 802.11 specification.
Example | :SYST:PASS MYpAssWord23

PASSphrase?
This command is not implemented, as it poses a security vulnerability for the WiFi network.
Command format | :SYSTem:PASSphrase?
Description | Returns a descriptive message.
Typical return | WiFi password can only be SET remotely.

CONNect

Command format | :SYSTem:CONNect <ON|OFF>
Description | Set the instrument to Autoconnect to the WiFi network. Turning this setting OFF effectively disables WiFi
Example | :SYST:AUTO ON

CONNect?

Command format | :SYSTem:CONNect?
Description | Return the autoconnect status
Typical return | 0 (OFF) or 1 (ON)

HOSTname

Command format | :SYSTem:HOSTname [string]
Description | This command sets both the name displayed on the web interface and the hostname component of its URL. The argument string should not be enclosed in quotes. The URL generated is not case sensitive and will be of the form hostname.local The unit may be addressed name as well as its IP address. The hostname will not change until the WiFi server is re-initialised. Restart, or follow this command with :SYST:AUTO OFF then :SYST:AUTO ON to change the web interface URL.
Example | :SYSTem:HOSTname myLoad mDNS will respond to ICMP (ping, DNS) requests to MYLoad.local or myload.local as URLs are case insensitive.

HOSTname?

Command format | :SYSTem:HOSTname?
Description | Return the hostname (same as Instrument name)
Typical return | myLoad

## SCPI Packet Structure

SCPI commands are sent as ASCII text and the command string is NULL terminated in the packet.

Transport (UDP/IP) Headers

Item | Type | Content
IP Header | 20 bytes | Source & Destination Address, Protocol
UDP Header | 8 bytes
Bytes | | Content | Location
2 | | Source Port (optional IPV4, IPV6) | 0-1
2 | | Destination Port | 2-3
2 | | Length | 4-5
2 | | Checksum (optional for IPV4) | 6-7

SCPI packet (follows UDP/IP headers)
Bytes | | Content | Location
4 | char | 'SCPI' | 0-3
4 | uint32_t | Pkt sequence number (0, other than for logging) | 4-7
2 | uint16_t | Message length (max 1024 bytes - to avoid jumbo packets) | 8-9
1 | int8_t | Tracking group (-1 is universal, e.g. all eStop) | 10
16 | char | Sender name or ID? | 11-26
Up to 1024 | char | Content (Always ASCII. SCPI commands and responses. CSV for logging). | 27-1050
1051 | Total | SCPI packet

## Design Overview

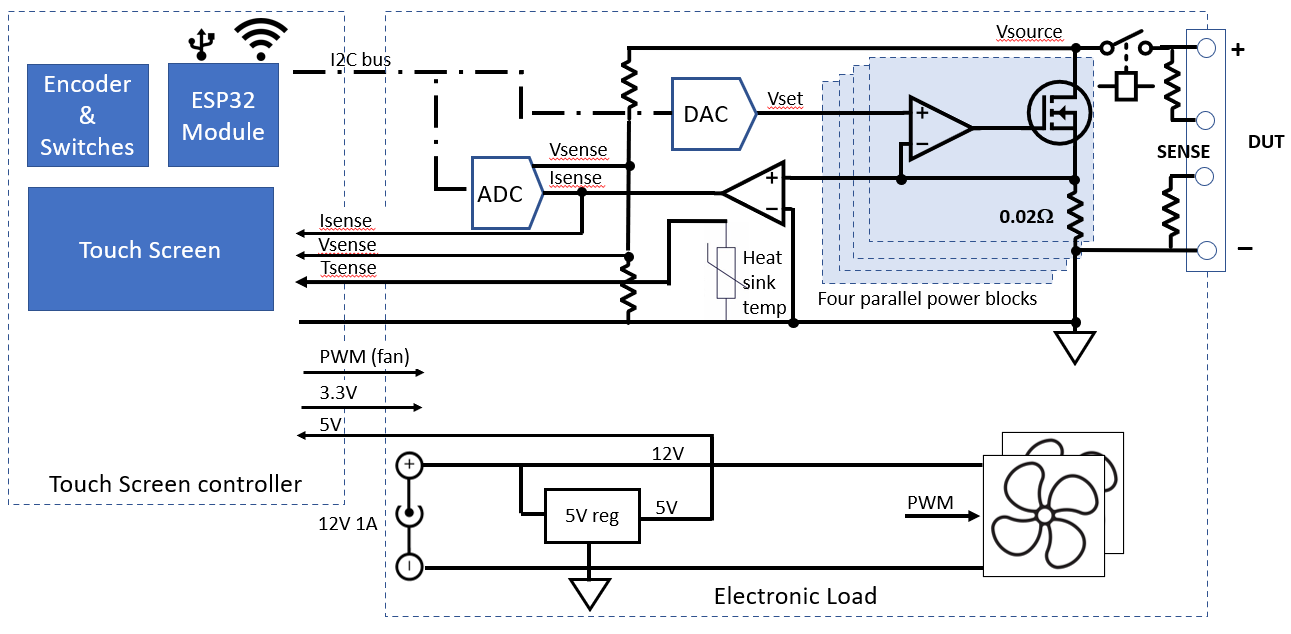
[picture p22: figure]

Fig.2. a simplified block diagram showing the major features of the load. Four identical op amp / MOSFET power blocks are controlled by a DAC. Input voltage and current are measued by an ADC. A relay can disconnect the load. The ESP32 module handles communications and control functions.

At the core of the design (Fig.2) are four power blocks, each with a MOSFET, a shunt resistor and some control circuitry. A control voltage, Vset, is provided to the power blocks by a shared DAC.

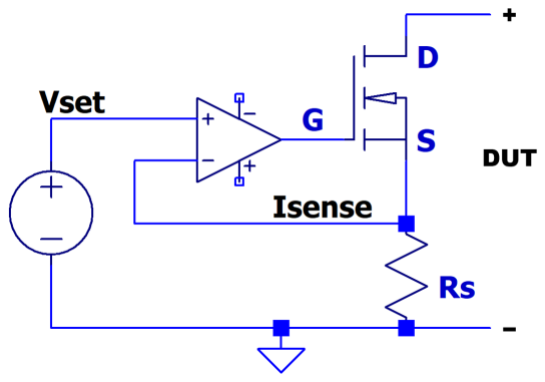
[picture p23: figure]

Fig.3. Basic constant current load circuit. The MOSFET drain current is reasonably proportional to its gate voltage, once the gate threshold voltage has been reached.

The voltages at the load’s input and across Rs are measured by an ADC. The microcontroller iterates Vset until the desired operating conditions are reached.

One of the MOSFET’s case temperatures is read by a thermistor and fed to an ESP32 ADC channel. This value controls both the fan speed, via a PWM signal from the ESP32, and over-temperature shutdown.

Power comes from a 12V plug pack which directly powers the fans and op amps. It is switched down to 5V to power the ESP32 controller and several load components. 3.3V is fed back from the controller to power the DAC and ADC. The general arrangement is the same as for the Hybrid Lab Supply project (SC May-June 2021).

To simplify mounting of the MOSFETs on the CPU coolers and arranging them inside the enclosure, one pair of MOSFETS and their cooler have been separated onto a separate daughter board. Power supply and control signals connect to the main load PCB via a short ribbon cable.

## Schematic

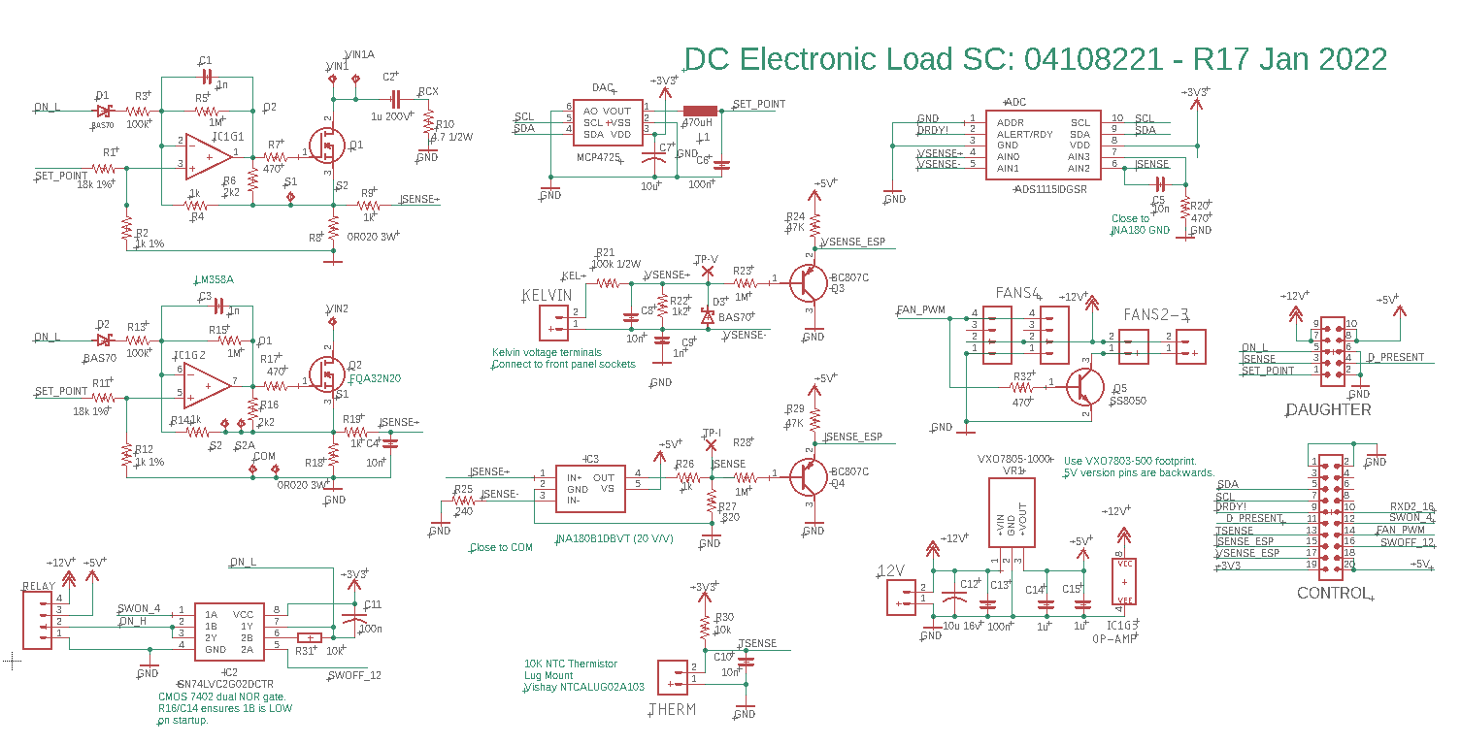
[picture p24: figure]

Fig.15 the main load board includes two power modules, based around IC1, Q1 and Q2; control and monitoring components including the ADC, DAC, IC3, Q3, Q4 and the thermistor TH1. The DAC sets the output current of Q1 & Q2. The input voltage and voltage across the shunt resistors R8 & R12 are amplified by IC2 and measured by the ADC. Current monitor IC2 controls the on/off functions of the MOSFETs and relay. A PWM signal to Q5 sets the fan speed.

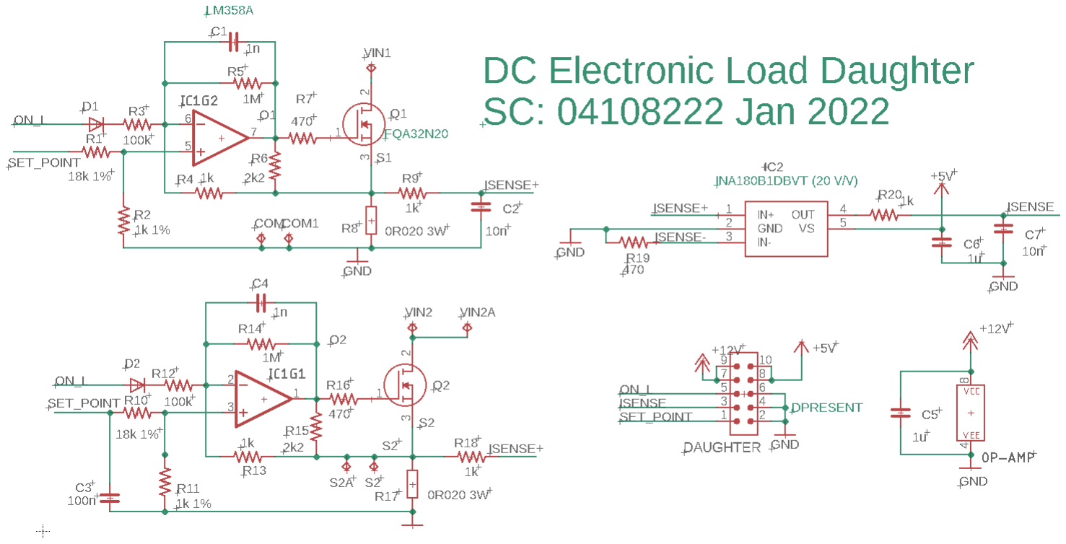
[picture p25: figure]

Fig.16 the daughter board comprises two power modules and a current monitor IC, identical to those on the main board. Control and sensing are transmitted to the main board via the daughter connector.

## Control header pins

ESP32 IO pins are not 5V tolerant. Only 0 – 3.3V signals should be connected to inputs.

GPIO outputs have a 12mA maximum current rating.

Header
Pin
ESP32 Function | GPIO | Header Pin
Function | GPIO
1 | GND | 2 | GND
3 | | 4
5 | SDA | 21 | 6
7 | SCL | 22 | 8
9 | DRDY! | 2 | 10
11 | D_PRESENT | 12 | SW_ON | 4
13 | TSENSE | 14 | FAN_PWM | 26
15 | ISENSE | 16 | SW_OFF | 12
17 | VSENSE | 18 | +5V (Supply)
19 | +3.3V (Return from ESP32) | 20 | +5V (Supply)

A Bill of Materials and construction details are included in the associated Silicon Chip article published in 2022.

## Specifications

Item | Value
Load power dissipation | 300W
Minimum resistance | 0.025 ohms (design)
Input Voltage | Operating: 0 – 150V Absolute maximum: 200V Resolution: 6mV above 100mV Linearity < 1% (above 150mV) when calibrated
Input current | Software limited to max rated dissipation (see Safe Operating Area and Protection) 30A max @ 3 - 10V 2A @ 150V 10A @ 1 V (min resistance) 2A at 200mV (min resistance) Absolute maximum: +/-35A (relay disconnect) Resolution: Set: 7mA Read: 1.5mA 0.2% measurement linearity when calibrated (> 200mA) Warning: Load will sink substantial current if reverse voltage is applied before disconnection (< 100ms).
Constant Current Mode | Set: 10mA – 30A Line regulation < 0.2% (>100mV & 20mA) Rise time (0.1-4A) < 200 uS Limited to max dissipation – see SOA curve
Constant Voltage mode | 50mV min
| Accuracy < 2% above 1V
Constant Power Mode | 0.1W to 300W 1V to 150V input Accuracy < 2% above 1W
Constant Resistance Mode | 0.2Ω to 999.99Ω Accuracy < 2% below 100Ω and above 100mA & 1V
Step Mode | CC, CV, CP, CR modes

THIGH, TLOW 5 mS – 32767 S

Rise/Fall: | zero setting: < as per CC mode
non-zero setting: 1 – 32767 mS

Limited to max dissipation – see SOA curve

Battery Test Mode | CC, CP and CR modes supported
Electronic Protection | Relay current disconnect time < 100mS
Voltage reading remains connected to DUT terminals.
Current | 30A (soft limiting)
35A (disconnects)
Power | 300W (soft limiting)
Voltage | 155V (disconnects)
Reverse Voltage | < -0.1V (disconnects)
MOSFET case temp. | 65ºC (disconnects)
DC input | 12VDC 1.5A double insulated.
Dimensions | 270mm x 210mm x 140mm
Weight | 2 kg

Communication and remote control

Command processing time

Average time for control
change or response after a single command is issued

< 30mS

A single waiting command processed every 20mS.

SCPI commands

Units accepted | Volts and millivolts [V | mV]. No unit specified is equivalent to Volts. Amps and milliamps [A | mA]. No unit specified is equivalent to Amps. Ohms Watts Seconds [S | mS]. No unit specified is equivalent to Seconds.

Remote control connections

WiFi | 802.11 b/g/n/e/i Auto-connect to the SSID/passphrase combinations provided on the COM menu. The five most recently used WiFi credentials are stored, and each is tried until a successful connection is made. Where connection to any of the stored WiFi LANs fails, a local WiFi network is created: SSID: ESPINST PW: ESPPW99X The IP address range provisioned on ESPINST, using DHCP, is 192.168.50.X DHCP IP addresses are used or provisioned in all modes. The current IP address is available on the COM menu screen. DNS name is hostname.local (each instrument implements an mDNS responder) (see SCPI command :INST:NAME and COM menu) Windows computers no longer recognise the hostname.local format. WPS is not supported.
Telnet | Port: 5025 SCPI commands accepted and results returned. Functionality has been tested with the open source software TestController Studio, and an instrument definition file for this software is included in the project’s downloads.
Web (HTTP) | A web interface allows most settings can be altered and most actions initiated. Calibration and Communication settings are not available via the web interface. Port: 80 http://IPaddress The page is and not secured or encrypted.
UDP (packet) | SCPI commands may also be received using UDP packets, although this mechanism is primarily designed for inter-instrument communication. Port: 8888 IP address or hostname as above. Packet specifications are outlined in the SCPI Packet Structure section.
Isolated USB Serial | Damage may occur if a non-isolated USB connection is used. Baud rate: 115,200 SCPI commands accepted and results returned.

## Troubleshooting

Symptom | Likely cause | Remediation
Touch panel not responding. | Touch panel is rotated 180° from LCD. | See the Touch Calibration section.
Touch not centred on buttons. | Touch panel out of register with
LCD.

See the Touch Calibration section.

Voltage or current screen reading
incorrect.
Calibration not completed. | See the Voltage and Current
Calibration sections.

Instruments in a tracking group not tracking.

Voltage &/or Current tracking mode not enabled

See the Tracking Screen section.

Can’t access instrument (Web page or Telnet) remotely. | Wifi not connected. Instrument has joined the ESPINST WiFi network, rather than the WiFi LAN. | See Communication Screen and Specifications – WiFi sections.
Can’t access web interface using hostname. | Duplicate hostname. On some WiFi LANs the hostname mode may not work due to router or operating system configurations. | Use the IP address found in the COMMs console menu.

## Battery Testing Data

The information below is offered as a guide only. Specifications for individual batteries should be obtained from the manufacturer.

Battery
type

Standard discharge
test current*

Nominal
cell
voltage

End of
discharge cell
voltage

Information from

Sealed
Lead Acid

Constant current
(10 hour rate* = 0.1C)
2.1V | 1.75V | Megger. Battery Testing Guide
LiPO | Constant current
(2 hour rate* = 0.5C)
3.6V | 3.0V | https://www.lipoly-battery.com/lipoly- battery-performance-standards/
LiFePO4 | Constant current
(2 hour rate* = 0.5C)
3.2V | 2.5V | https://en.wikipedia.org/wiki/Lithium_iron_p hosphate_battery
NiCd | Constant current
(10 hour rate* = 0.1C)
1.2V | 1.10V | SBS. NiCad Battery Capacity Testing Procedure
NiMH | Constant current
(10 hour rate* = 0.1C)
1.2V | 1.0V | https://m.greenway- battery.com/news/NiMH-Battery-Voltage-- Checking-And-Voltage-Range-964.html

* A common value. Some batteries are rated at a higher or lower discharge rate.
The 10-hour discharge rate (amps) is the amp hour capacity of the battery divided by 10.

### Sealed Lead Acid Battery Characteristics

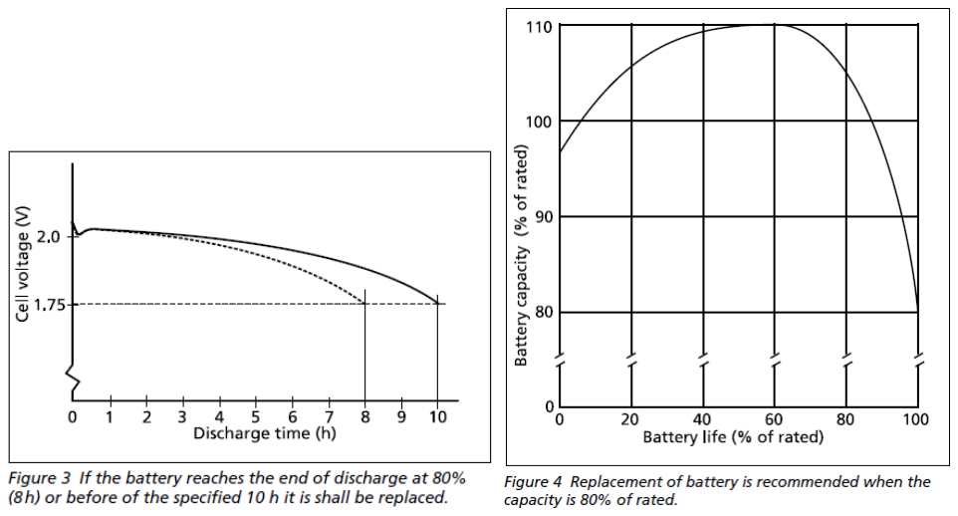
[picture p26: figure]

Diagrams are from the Megger Battery Testing Guide: https://megger.com/products/archive/proactiv/technical/battery-testing-guide

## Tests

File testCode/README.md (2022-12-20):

This code 
* does an I2C scan reporting all devices found
* periodically steps through a range of DAC values, reading and printing the ADS1115 and ESP32 ADC values as it goes

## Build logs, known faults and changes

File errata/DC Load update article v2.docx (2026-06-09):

# WiFi-Controlled Programmable DC Load Update

### Avoid Kelvin sensing until unit is modified

It is strongly recommended that the Kelvin voltage sensing function of the DC load is not used until the modifications outlined in this article have been completed. Normal voltage sensing, via the main + and – terminals is unaffected by this issue.

The WiFi Controlled DC Load project has proved popular, and constructors have suggested a number of worthwhile hardware and software improvements. Two stand out, principally Erwin Bejsta’s improvements to the battery test function, and Ray Miller’s analysis that showed that the original Kelvin voltage sensing arrangements could potentially damage the ADS1115 ADC at high currents. There is no issue if the main + and – terminals are used for voltage sensing.

The hardware changes

- Kelvin sensing issue rectified
- Reduced noise in the 12v supply
- Less control sensitivity to short-term current transients

While the full list of software changes is available in the changelog <link> the highlights are:

- Multiple improvements to battery testing
- Kelvin sensing modes added
- More accurate and rapid control behaviour, particularly in CR, CP and CV modes.
- Improved error condition monitoring (over/under voltage, over current, exceeding AOA).
- Screen rotation now supported as well as touch panel rotation.

Several other constructors have made suggestions that have been included in a software update which is downloadable from <link> and a revised manual is available at <link>.

# Hardware improvements

The main improvement to the hardware resolves the issue with Kelvin voltage sensing. This change is mandatory if Kelvin (4-wire) voltage sensing is to be used.

The other changes require one or two components to be added or changed: improvements to noise on the 12V supply rail to the opamps; a reduction in sensitivity to current transients in ESP32 readings and a reduction to ringing in the DAC output under step changes.

### Kelvin sensing modifications

Some additional circuitry is required to rectify the issue with Kelvin voltage sensing. In the original circuit, the negative Kelvin sensing terminal is connected directly to the negative input of the ADS1115. If Kelvin sensing is being used and there is significant resistance in the lead from the DUT to the main negative input, the negative Kelvin terminal develops a potential below system ground (see Fig.1).

If the load current is 10A, just 0.1 ohms resistance in the negative power lead will create a -1.0V potential at the ADS1115 negative voltage sensing pin and destructive current will flow, as the protection diodes in the ADS1115 are only rated at 10mA.

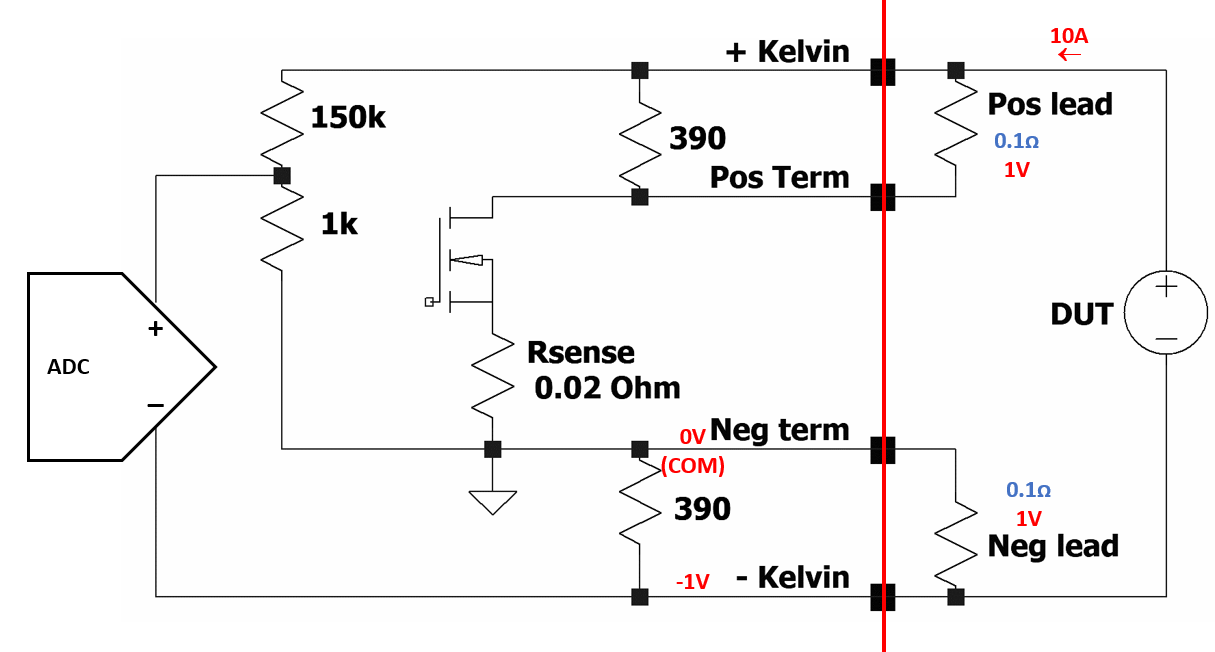
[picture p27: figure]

Fig.1 Simplified circuit of the original DC Load final stage and Kelvin sensing. When substantial current is flowing, any resistance in the negative lead to the DUT will induce a negative voltage directly at the ADC negative input.

To resolve this issue, a voltage divider is inserted into the negative side of the voltage sensing circuit and both positive and negative sides are biased to 0.7V (see Fig.2). This is sufficient to maintain both ADS inputs within acceptable values for normal operations.

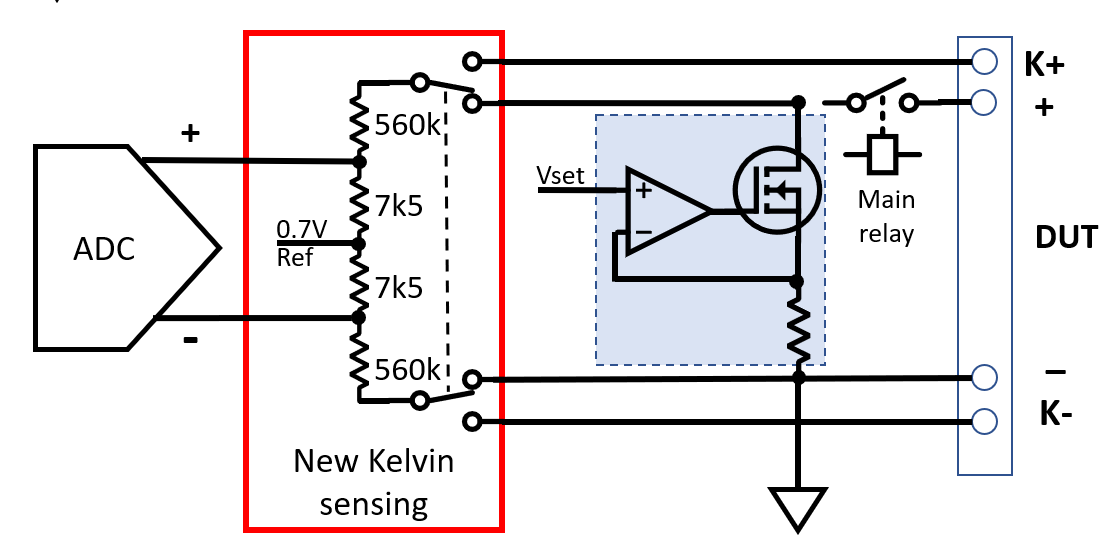
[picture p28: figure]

Fig.2 With a voltage divider in the negative Kelvin sensing leg, with -150V applied directly to the K- input, the current through the voltage divider is around 250uA, well with in the 10mA rating of the ADS1115input protection diodes.

The worst-case fault conditions are when the main negative terminal is disconnected. If the DUT provides 150V, the Kelvin terminal will be at -150V and the divider current is around 0.25 mA, well within spec for the ADS’ internal protection diodes.

A DPDT relay switches between the main and Kelvin voltage sensing terminals, removing any connection between them. The relay is driven by GPIO-16 via transistor Q1.

There are three voltage sensing modes available on the SET menu in the updated code: Main, Kelvin and Auto.

When the load is OFF, voltage is always sensed via the main terminals. With no current flowing, this will be the same value as the Kelvin terminals if they are connected.

When transitioning to ON, a measurement is taken on the Kelvin inputs. In Auto mode, if the voltage is close to the voltage across the main terminals, then Kelvin sensing is used. In Kelvin mode, if an equivalent voltage is not read an error is triggered and the load does not switch on.

The new circuitry in Fig.3 fits on Veroboard, Fig.4, which can be mounted near the relay board in the bottom of the case. There is no capacitor from K- to GND on the circuit as there is already a 1n MLCC in this location on the main Load PCB.

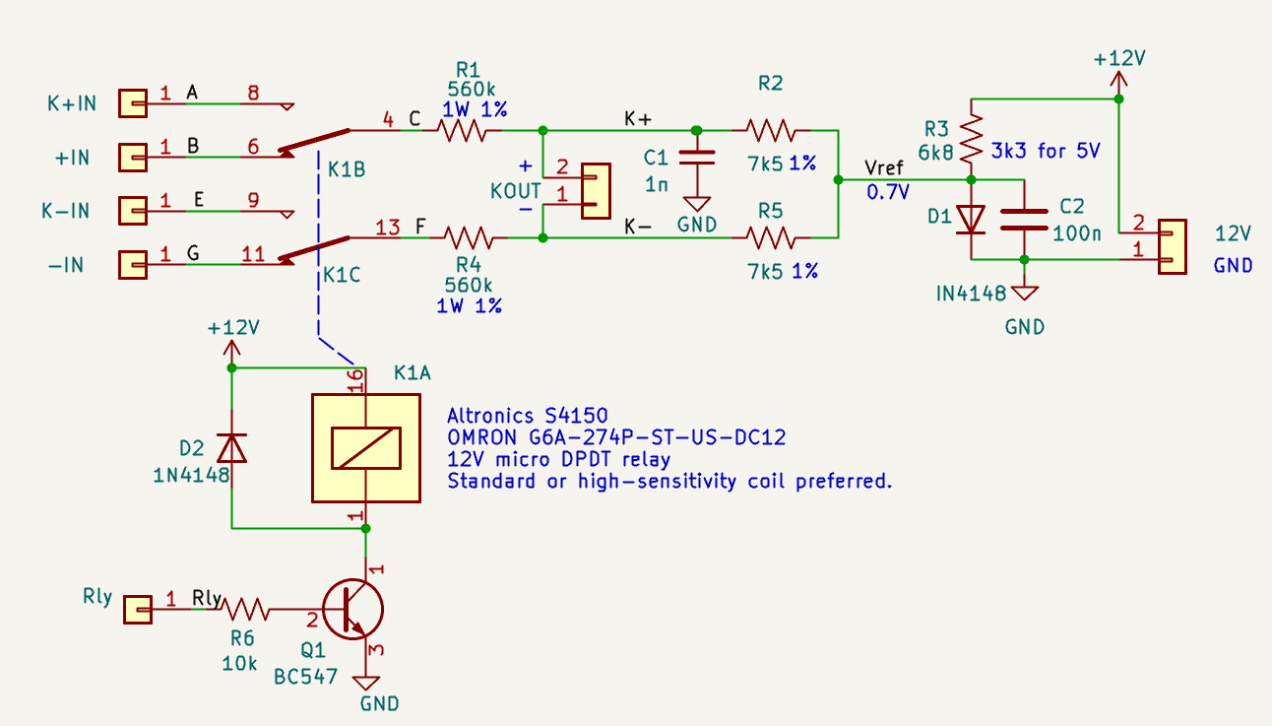
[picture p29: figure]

Fig.3 The components for the small cirucit containing the revised Kelvin sensing input circuitry. Through-hole components have been used to simplify parts sourcing.

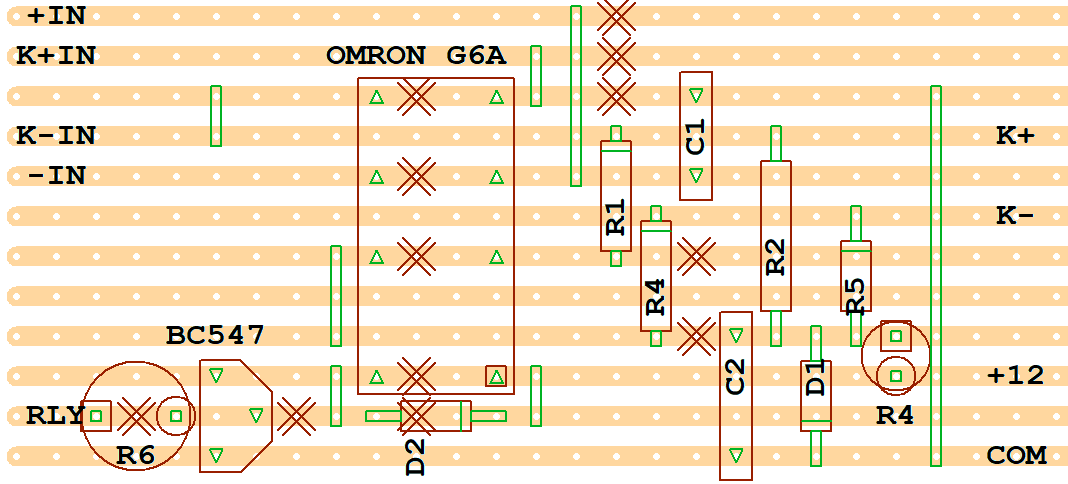
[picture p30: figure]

Fig.4 A Veroboard layout made with VeeCAD. The X marks are cut tracks. Green rectangles are links.

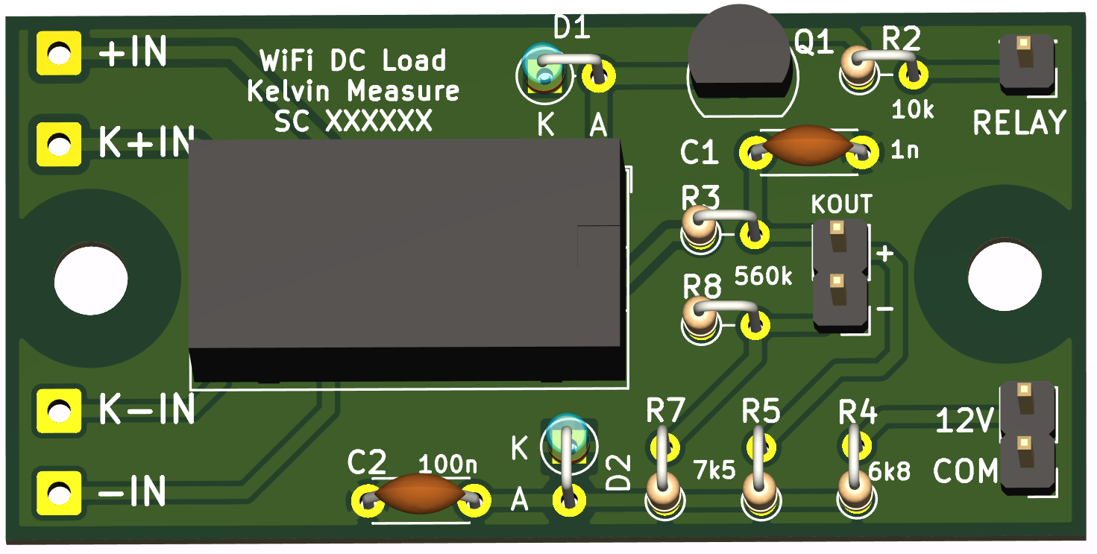
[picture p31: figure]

Fig.4 Alternately, the Gerber files for a 25mm x 51mm PCB are included in the repository.

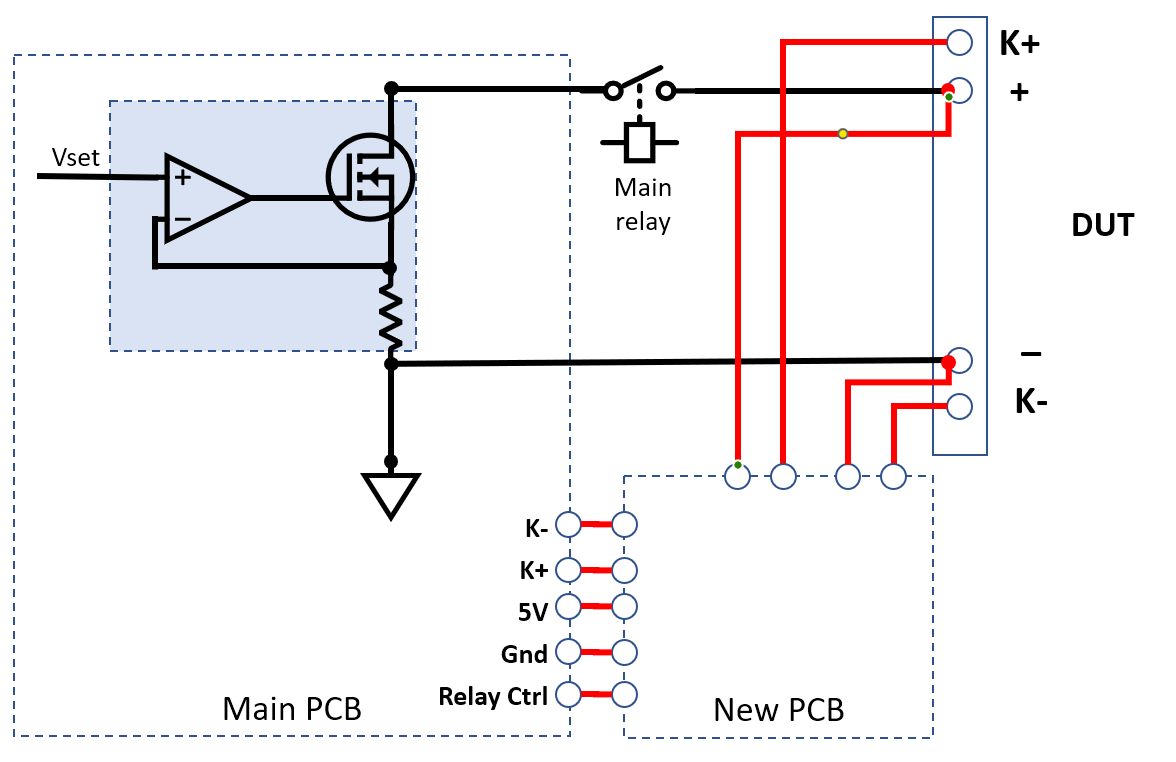
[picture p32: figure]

Fig.5 The new Kelvin sensing arrangements re-route the Kelvin sensing input wires and source additional signals from the main PCB.

### Construction

Through-hole parts have been specified throughout to simplify sourcing.

The DPDT micro relay has an Omron G6V footprint and drop in replacements are available from Altronics and other parts suppliers.

The 560K resistors need to be 1W types for their higher breakdown voltage. These and the 7.5K resistors in the voltage dividers are the only critical values in the circuit.

While we have designed a small PCB for this modification, Veroboard is a viable alternative.

The modifications to the main PCB are straightforward – the 100k ohm resistor in Figs 5 and 6 is bridged and the 1.2k ohm resistor removed. A 330pF capacitor is soldered between the base of Q5 and ground.

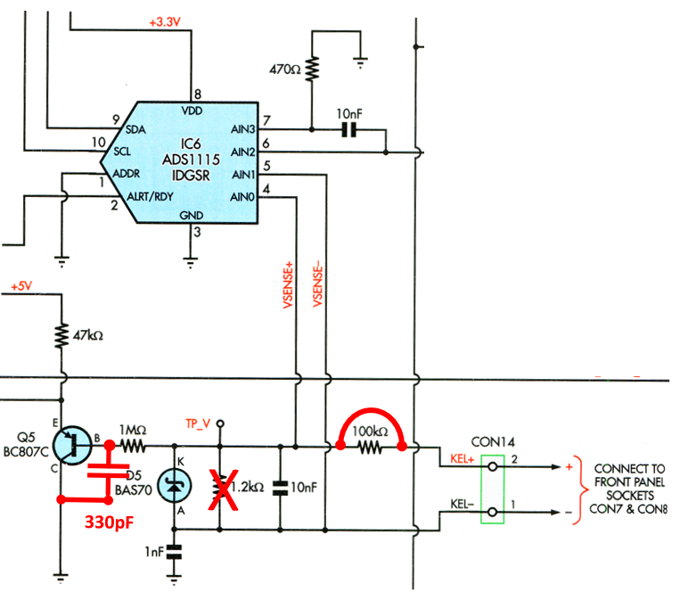
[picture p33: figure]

Fig.5 On the main PCB, one resistor is removed and one is bridged. A 330pF capacitor is added at the base of Q5 to reduce input noise to the ESP32 ADC.

The two existing 100 ohm resistors between the front panel Kelvin sensing and main input terminals are also removed.

While none of the wiring will carry any substantial currents, the + side wires coming from the front panel may be carrying up to 150V, requiring adequate insulation.

The two wires coming from the Kelvin terminals on the front panel are transferred to the new PCB (K+IN and K-IN pads) and the KOUT pads of the new PCB go to the main PCB’s Kelvin terminals.

The four input pads on the left-hand side of the board connect directly to their respective front panel terminals.

The relay signal comes directly from pin 8 of the Control connector, 12V and COM are available on the main PCB. The Relay pins on the main PCB are a convenient source.

After connecting all the cables to the small PCB, mount it in the base of the case, next to the main relay board.

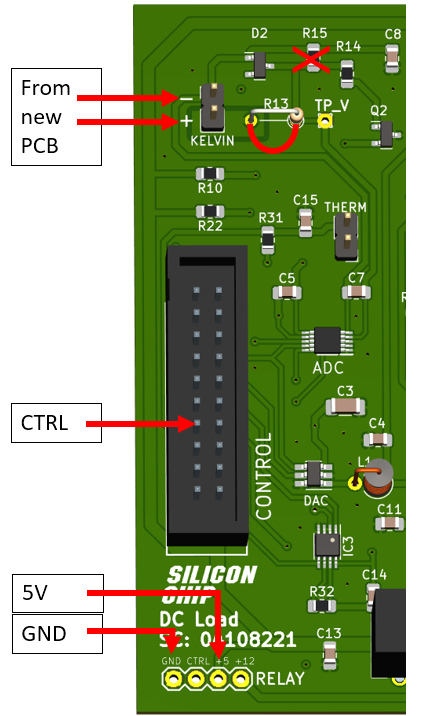
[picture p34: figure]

Fig.7 A visualisation of the main PCB alterations.

### Current transients

Ray Miller detected load current transients, followed by ringing in the current control cycle, that were triggered by false current readings by the ESP32 ADC (see Scope.1). The deviations from the correct value are +/- 30mV indicating a current variation of just over 0.5A.

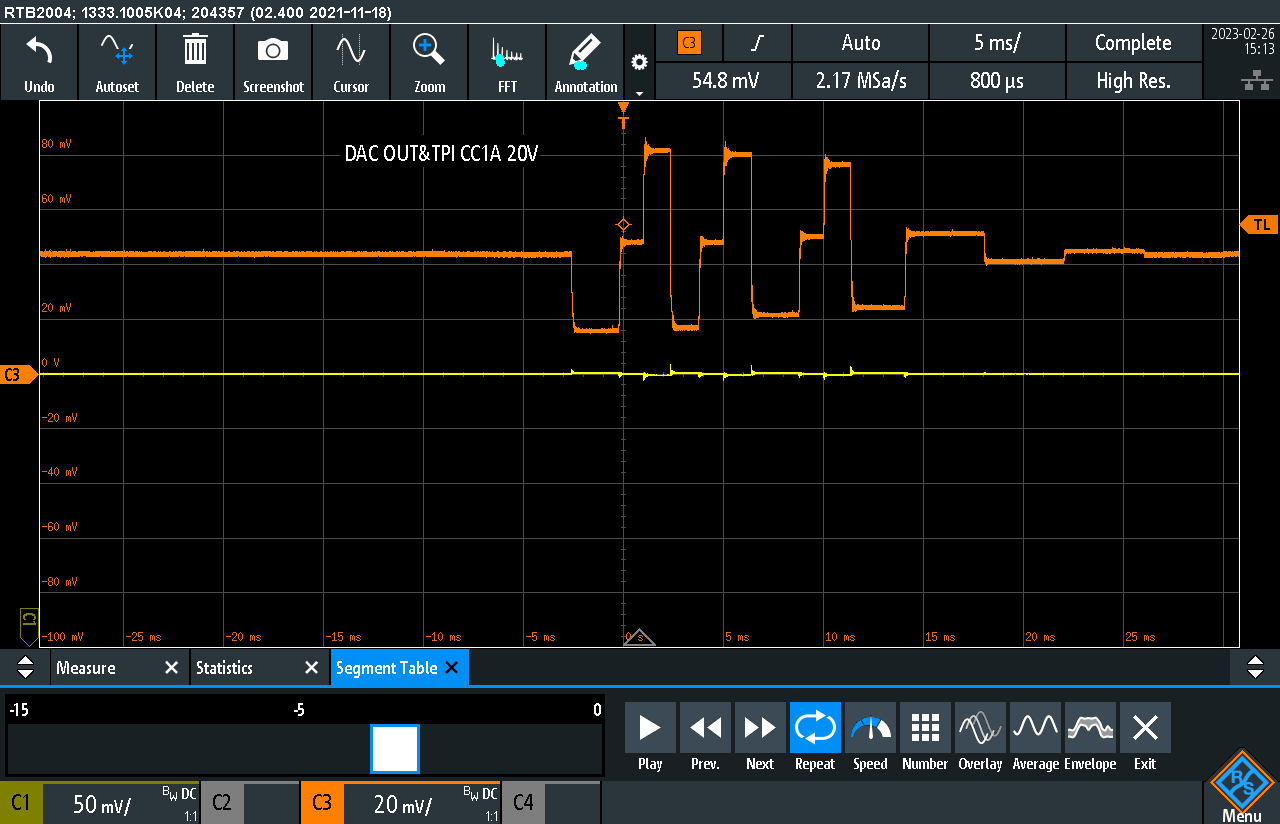
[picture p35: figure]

Scope.1 Ray Miller’s capture of the current waveform resulting from the transient ESP32 current reading. The orange trace is the current at test point TP-I and the yellow trace is the voltage at TP-V. The vertical resolution is 20mV/div and horizontal 5mS/div.

The main ADS1115 ADC completes a set of readings every 2.3mS. In between these cycles the ESP32’s ADC is used to check that there hasn’t been a substantial change to current or voltage that needs immediate attention. In the scope trace, Scope.1, a transient high current reading by the ESP32 ADC, around 3mS before the cursor on the screen, caused a substantial downward change to the DAC current setting, as shown in the top trace. The next ADS sample corrected the issue; however the control loop was not sufficiently damped and it took several control cycles before the output settled.

The issue has been rectified in software: the current difference that will cause an immediate update after a substantially different ESP32 reading has been increased from 0.4A to 5A. While the new value may seem large, instantaneous current control is managed by the op amp driving each MOSFET and the ESP32 ADC readings are mainly intended for more immediate response to short-circuits.

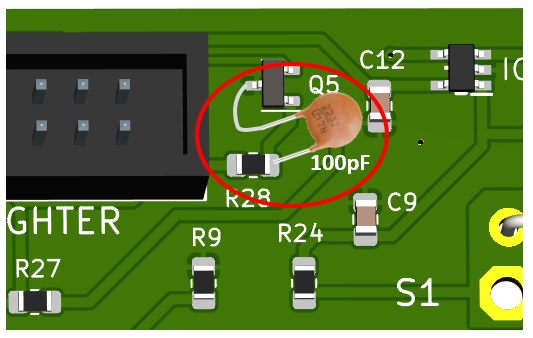
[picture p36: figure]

Fig.6 100pF is added between the base of Q5 and ground on the main PCB to reduce transients in the ESP32 ADC current signal.

To further reduce the sensitivity to transients, Ray Miller’s suggestion of a small (100pF) capacitor from the base of Q5 to ground (see Fig.X) offers a worthwhile improvement.

### Power supply noise

The fans on the CPU coolers produce quite a lot of electrical noise. While there is no observed connection to the load’s performance, decoupling the 12V supply to the op amps from the 12V input could be useful. The12V track (see Fig.X) on the rear of the main PCB is broken and a ferrite bead is inserted into the 12V line. Next to it, add 1uF MLCC from the decoupled track to ground.

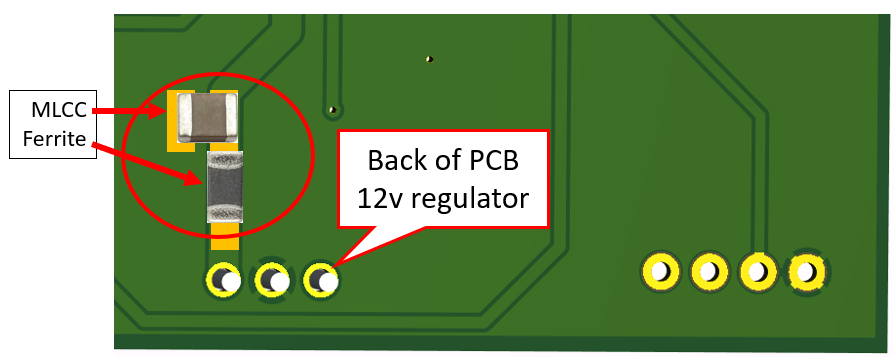
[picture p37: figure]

Fig.x On the underside of the PCB, break the 12V track near the pin of the regulator and insert a ferrite bead across the gap. A 1uF MLCC provides extra filtering of the decoupled supply.

### Opamp output

Another of Ray’s observations was that the input to the opamps exhibited some ringing under step changes (Scope.2) at the resonant frequency of L1 and C4 . Replacing the choke with a 47 ohm resistor rectifies the issue.

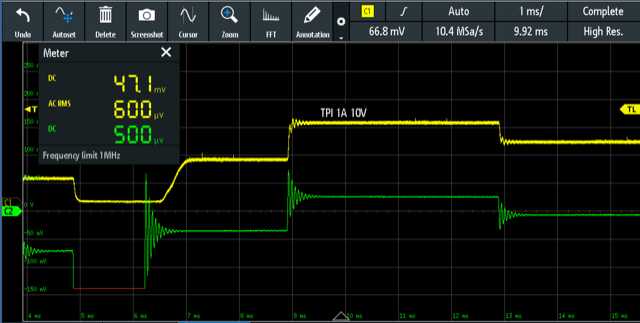
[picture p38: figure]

Scope.2 Ringing at the input to the opamps due to L1 and C4

# Software improvements

### Battery test improvements

There are three main improvements in the battery testing code, none of which require any circuit modifications.

Occasionally the battery test would drop out early due to a single voltage measurement below the test completion setting. Now the code averages several readings before deciding whether the final voltage has been reached.

The screen summarising the results of the battery test previously disappeared after 10 seconds, which was not optimal for unattended testing. Now the summary screen remains visible until the user touches the screen.

The measurement logging rate has been decreased is now able to be set via the logging interval (LI) setting (1 to 999,998 seconds) and the buffer size increased, allowing hundreds of hours of test duration before values start to be overwritten in the circular log buffer.

### Screen rotation

Several constructors noted that their screen displays were upside down, requiring re-compiled code to be provided. An option in the CAL menu is now available for rotating the screen display as well as the touch panel.

## Parts List

1 double-sided PCB coded 1234567, 24 x 42mm

1 micro DPDT relay with 12V coil (Omron G6A-274P-ST-US-DC12 (https://au.mouser.com/ProductDetail/Omron-Electronics/G6A-274P-ST-US-DC12?qs=Rh%252BaoYk36r7iaQnjgsLerg%3D%3D), Altronics S4150)

2 GP silicon diode, 1N4148 or similar

1 NPN GP transistor (CBE), BC4547 or similar

2

### Resistors (All 1/4 W metal film, 5% or better unless noted)

3 7.5k, 1%

1 6.8k

1 10k

2 560k, 1%

### Capacitors (radial ceramic)

1 1 nF

1 100 nF

1 330 pF

### General improvements

The fans create significant electrical noise on the 12V supply and some of the high frequency components of the noise find their way through the op amps to the MOSFET gates. A small, 50-150uH RF choke and 10uF MLCC are inserted into the supply line as shown in Fig.x to isolate the 12V supply to the analogue portions of the circuit.

The choke at the output of the DAC which reduces supply line noise on the control signal also causes some ringing during step changes. It can be substituted by a 100 ohm resistor to eliminate the ringing.

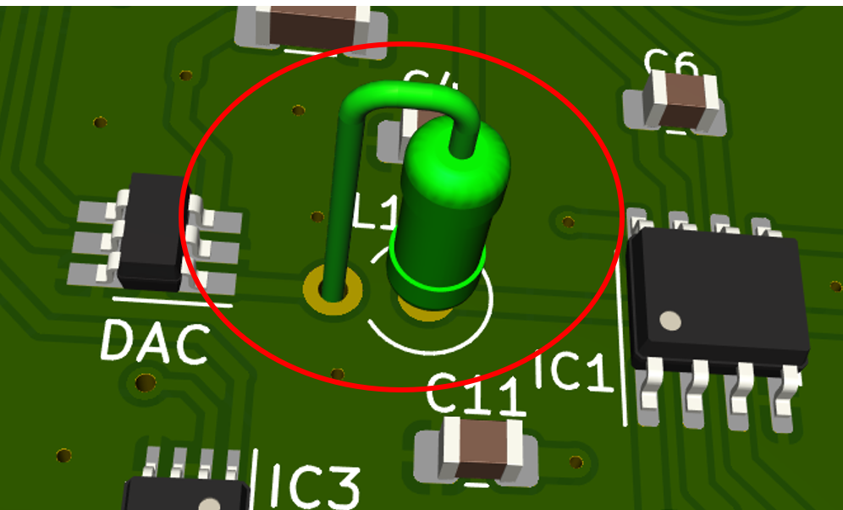
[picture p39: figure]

Fig.x The inductor on the output of the DAC is replaced by a 100 ohm resistor to eliminate ringing during step changes.

Jaycar LF1534

10uF 25V MLCC

100 ohm ¼W resistor

### Open-source code

Several constructors have asked for the code to be made available, so that they can improve or extend it. The original and improved code, as well as compiled binaries, are now available at https://github.com/palmerr23/ESP32-DCLOAD Compiling from source, however, is not for the faint hearted!

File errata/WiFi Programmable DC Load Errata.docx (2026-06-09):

# WiFi Programmable DC Load

# Two issues with initial run of main PCB (SC 04108221)

## 1. Ground via too close to track

A ground via has been paced too close to the SDA track. The via is across from pin 14 on the CONTROL connector and just above the DAC

The issue can be corrected, as in the photo, by carefully disconnecting the top of the via from the track and ground plane with a small (2mm) drill bit.

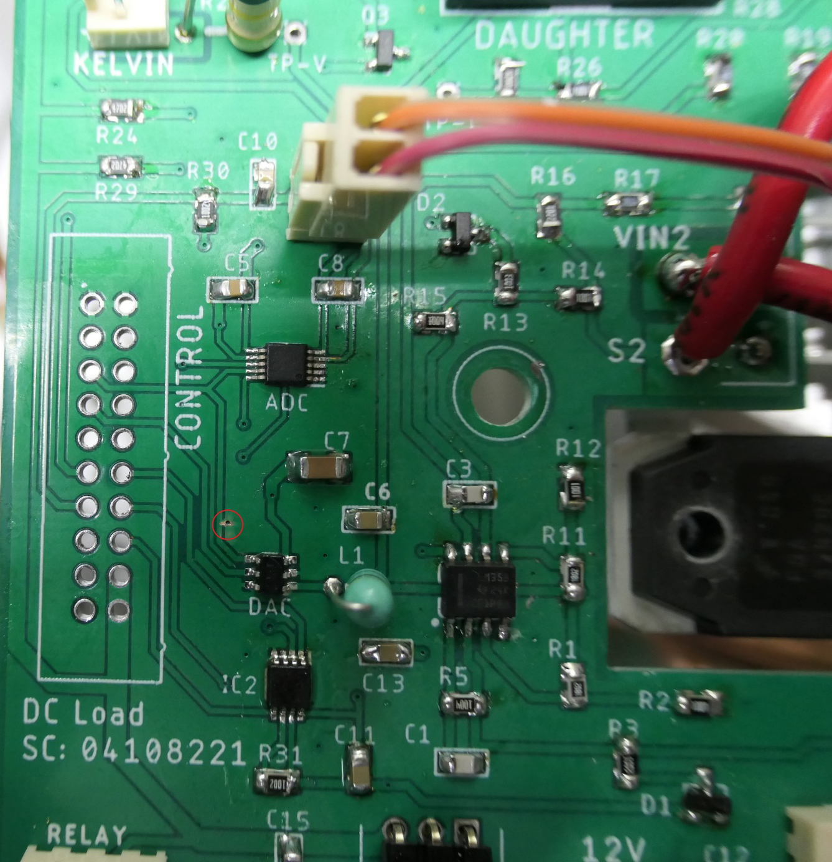
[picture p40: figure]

2

1

## 2. Regulator orientation is incorrect and heatsink may be required

The 7805 regulator pin markings are reversed on the silkscreen overlay. Input Pin 1 should go to the right, connecting to the 12V input terminals.

The prototype used a VXO7805 switching regulator and no heatsink was specified when the parts list was amended to a 7805 regulator. A small flag heatsink may be required. A ‘touch test” will indicate whether a heatsink is required.

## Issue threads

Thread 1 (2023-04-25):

Touch is mirrored in horizonal axis

derwhalfisch, 2023-04-25:
In both touch orientation settings (1 and 3) the touch is not correct. Mode 1 is 'rotated' appropriately but it still mirrored in x/horizontal direction.

palmerr23, 2023-04-25:
I've used many different brands of screen across a number of projects and this is the first time anyone has reported a touch panel that is _mirrored_!

Just to check - is the display the right way up, and displaying correctly (some folks have reported screens that are rotated)?

The firmware is the latest published one, and I'm working on several improvements suggested by constructors.

I can't see an easy fix to a mirrored touch panel, but I'll think on it.

BTW: don't use the Kelvin voltage sensing - there's an issue with it.

derwhalfisch, 2023-04-25:
Hi

I've just flashed your v3 bin on again to check. I have SROT=1, TROT=3 and the touch is mirrored in x-axis.

I found in myLScreenCal.h, line 127 that the tsrot is basically constrained to 1 or 3; 	sc.tsRot = (sc.tsRot + 2 ) % 4;

so I changed this to 	sc.tsRot = (sc.tsRot + 1 ) % 8; hoping that one of the other modes would be useful but I didn't have any luck. It won't draw numbers higher than 4 either (shows "***" instead) so I may not have even been testing all 8 modes.

palmerr23, 2023-04-25:
I wouldn't have expected further _rotations_ of wither the screen or touch pad to fix a _mirroring_ issue.

Also, I don't think there are more than 4 modes available in the XPT2046:

Line 62 in XPT2046_Touchscreen.h
	void setRotation(uint8_t n) { rotation = n % 4; }

It's worth checking that the touch controller is actually an XPT2046. If not, an alternate driver might do the trick.

What I'm thinking is that it might be possible to subtract the read X position from the maximum before checking whether a block is touched in  myLtouchprocess.h after line 217
p = ts.getPoint();
#ifdef MIRROR_TOUCH
p.x = 4096 - p.x; // might need to be sc.thmax rather than 4096, as my screen edge is at 3900 counts
#endif

derwhalfisch, 2023-04-25:
I probably misinterpreted another discussion I found of the XPT2046 in which they were discussing 3 bits that described the orientation, and in which there was a reflection issue also.

I do need the screen rotation capacity of the latest firmware but I'll see if i can try your suggestion here in the v2 codebase.

Thanks for the help, I'll come back with the result.

derwhalfisch, 2023-04-25:
I found the discussion I misunderstood: https://github.com/Bodmer/TFT_eSPI/issues/96#issuecomment-367720292

Your addition of subtracting p.x from sc.thmax works. I haven't look to see where thmax is from, so I will also try 3900 and 4096, but not this evening.

palmerr23, 2023-04-26:
sc.thmax is set by the screen calibration routine myLScreenCal.h , and defined in myLScreenDefs.h around line 127

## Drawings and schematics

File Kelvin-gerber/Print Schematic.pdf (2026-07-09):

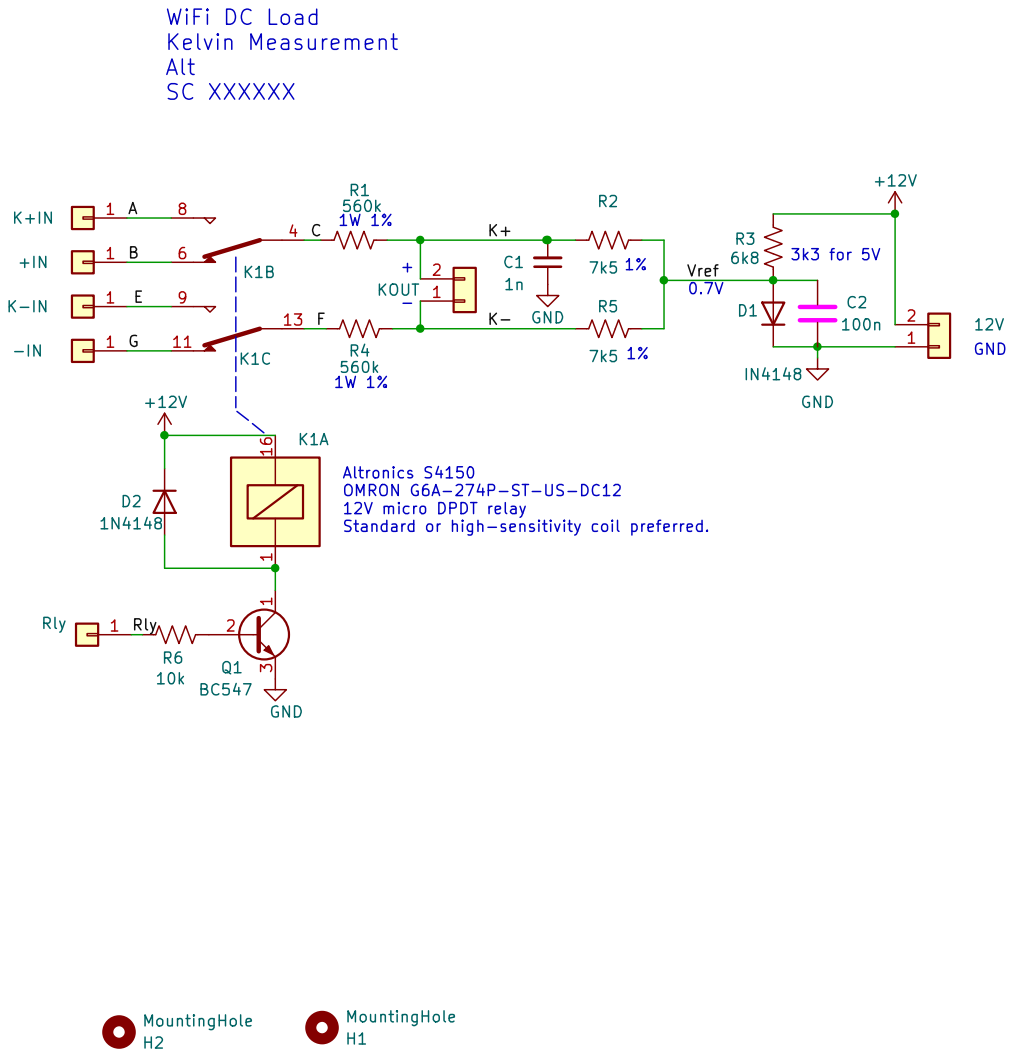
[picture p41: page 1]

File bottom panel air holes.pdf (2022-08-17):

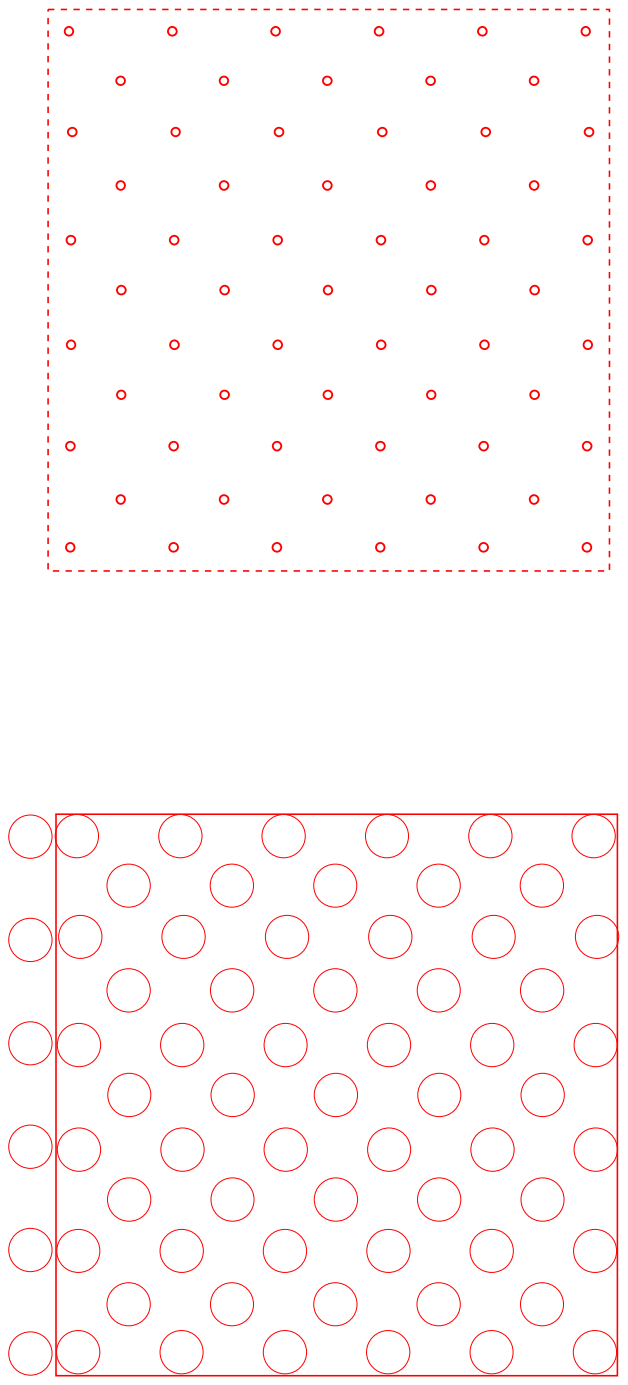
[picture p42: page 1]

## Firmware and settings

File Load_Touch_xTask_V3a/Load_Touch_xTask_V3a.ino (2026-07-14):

// V1.3aR5a
#define PROD
#define SOFT_VERSION 4
#define KELVIN_MOD // Redefines a few default calibration settings
/* REMEMBER TO SET DISPLAY TYPE BEFORE COMPILING
 * compile with Board "ESP32 Dev Module" and  Partition "Minimal SPIFFS (1.9Mb with OTA / 128kB SPIFFS)"
 * controlTask() is driven by ADS1115 interrupts, watchdog in main code for lost interrupt 
*/
#define  ILI9488 // select one
//#define  ILI9341 //
#define SAVEBATLOG  // after battery test use the battery log when saving log file via http 
//#define BOARD_D 

// diagnostic options
#define WIFI    // faster startup for testing if WiFi is off. May also disable serial SCPI.
//#define REALNET // use network credentials from a file for WiFi testing
//#define NO_ERRORS // don't show screen Error messages - for testing basic TFT functions
//#define C_DEBUG // slow down control execution and enable serial diagnostics, for testing
#define PROCESS_EVERY_CDEBUG 20 //  
//#define PRINT_DIAGNOSTICS
//#define SOATEST // reduce I, V and P max values for testing SOA code. Recompile with different software version when changing this.
// end of diagnostic settings

#ifdef PROD
  #define SPLASH    // turn on for production
  #undef C_DEBUG    // ensure all diagnostics are off
  #undef PRINT_DIAGNOSTICS
  #undef SOATEST 
  #undef REALNET
  bool _printMe = false;
#else
  bool _printMe = true;   // diagnostic prints during testing 
#endif

// ADS watchdog
#define ADS_WATCHDOG 10    // (mS) restart ADS cycle interrupts get lost (ADS interrupt cycle ~ 1.2mS @ 860sps)
volatile long adsLastInt;
volatile long controlTime = 0;
volatile long controlLoops = 0, lastLoops = 0;
int adsCount = 0;
bool startUp = true;
bool _scrTouched = false;  // was the screen touched?
bool newScrError = false; // for non-blocking version of screenError
bool holdScreen = false;  // don't update screen while this is true (screenError)

#include <esp_task_wdt.h>
#include "myLInst.h"
#include "myLoad.h"
#include "myLESP32.h"
#include "myLHelpers.h"
#include "myLScreenDefs.h"
#include "myLSwitches.h"
#include "myLADS1115.h"
#include "myLADS1115bits.h"   
#include "myLPOST.h"

void printfloat(char fmt[], float val, uint16_t highlight, uint16_t x, short y, uint16_t txtcol, uint16_t highcol, uint16_t bgcol);
int readADC(int ADCpin, bool printMe = false);
//long loopcntr;
//#define TESTPIN FANPIN
bool myBlink = false; // set by timer at same time as regular redraw
bool testPin = false;

#include "myLScreenDraw.h"
//#include "myLWifi.h"
#include "myLWifi_multi.h"
#include "myLTelnet.h"
#include "myLUDP.h"
//#include "myLHTTP.h"
#include "myLHTML_literal.h"
#include "myLHTML_processor.h"
#include "myLwebserverSPIFFS.h"

#include "myLADC_DAC_PWM.h"

#include "myLControl.h"
#include "lscpiparser.h"
#include "myLSCPI.h"
#include "myLProfile.h"
#include "myLSPIFFSProfile.h"
#include "myLlog.h"
//float vTarget = VSTART;
//float iTarget = 0.08;
//float eTrack = 1.0;
//int setting = WSTART;

long lTimer, mTimer, fTimer, vfTimer, vTimer, cTimer, tTimer, tUsec, cdTimer, lcount = 0; // various processing frequency timers for loop()
#define NBUCKETS 100
//int timeBucket[NBUCKETS];
//long fineTime;

// xtask params
TaskHandle_t controlTaskHandle;
xTimerHandle controlCycleTimer;
#define TIMER_TICK  1     // mS per tick. 
#define TIMER_CYCLE 1     // Control cycle time. Something less than the ADS measurement cycle to allow intermediate ESP readings.

#define C_STACK   18000  // Stack size for control task
#define TASK_CPU  1      // beware of changing this from the same core as Arduino - may cause watchdog errors 
#define TASK_PRI  15     // higher number than loop() == 1

long controlStart;

void setup() {   
  newPosition = 0; 
  Serial.begin(115200);
  delay(1000);
  Serial.println("*********** Starting DC Load Control *************");

  screenBegin();
#ifdef SPLASH
  splashScreen();
#endif

  if (!post())
     (postBuf, MY_RED, 10, false); // 3 x I2C for single (7 for dual);

for(int i = 0; i < NUM_CALS; i++)
    hal_defs[i] = halCal[i];  // copy factory defaults into temp storage in case a reset is needed
/*
  EEPROM.begin(EESIZE + 5 ); // maybe a few additional bytes will stop the kernel panic restart on save
  if (!setupEE()) // read values from EEPROM
  {
      screenError("Bad EEPROM read\nFailed factory reset\nAborting", MY_RED, 10, false);  
      // should probably shut things down
  }

*/
 // EEPROM.begin(EESIZE + 5); Serial.println("Factory reset"); factory_reset(); // When all else fails - uncomment and reset EEPROM
  if(!beginEE())
  {
     Serial.println("EEPROM unreadbale after factory reset - should possibly halt!");
     screenError("Unable to read EEPROM after\nFactory reset", MY_RED, -1, true);
  }

  if(!LittleFSstart())
    screenError("File system failure", MY_RED, -1, true); 

  Serial.printf("tsRot %i, scRot %i\n", sc.tsRot, sc.scrRot);
  ts.setRotation(sc.tsRot); // some displays have a rotated touch panel (CAL menu)
  tft.setRotation(sc.scrRot); // some displays have a rotated screen (CAL menu)
  
  // set up control pins, ISR and other hardware-related initialisation
  control_setup(); // daughter board sensing

  // comms params from SPIFFS profile.json - must run after Settings read from SPIFFS (overwrite comms in myID)
  if(getComms()) 
  {
    updateWiFi(myID.local_ssid, myID.local_pass, true);
    //printStoredWiFi();
  } 
  else
  {
    screenError("Unable to read profile in file system\nFile restore needed", MY_RED, -1, true);
  }

  // xTask for control()
  // 
  //Serial.println("xTask");  delay(1000);
  //pinMode(TESTPIN, OUTPUT);
  /*
  for(int i = 0; i < 5000; i++)
  {   
     testPin = !testPin;
     digitalWrite(TESTPIN, (testPin)? HIGH : LOW);
     delay(1);    
  }
  */
    // start the regular conversion process
  attachInterrupt(digitalPinToInterrupt(ADSRDY), ads_ISR, FALLING);
 // Serial.println("ATTACH int done");
  //  delay(100);  
   controlStart = micros();
   adsReady = false;
   adsReadStart(); // start the ADS (restarted after interrupt in controlTask, watchdog in loop())
 /* Serial.print("<");
  esp_task_wdt_config_t wdt_config = {
    .timeout_ms = 10000,     // 10 seconds in milliseconds
    .idle_core_mask = 0,     // don't watch idle tasks
    .trigger_panic = false    // reset (panic) if watchdog fires
  };
  esp_task_wdt_init(&wdt_config);

  Serial.print(">");
    */
   // Once controlTask() is running, no I2C commands should be issued in any other routines to avoid conflicts
    xTaskCreatePinnedToCore(controlTask, "cTask", C_STACK, NULL, (TASK_PRI | portPRIVILEGE_BIT ), &controlTaskHandle, TASK_CPU);

  //controlCycleTimer = xTimerCreate("timerC", pdMS_TO_TICKS(TIMER_TICK), true, (void*)0, controlCallback); // auto reload timer
  //xTimerStart(controlCycleTimer, TIMER_CYCLE);

 Serial.print("#");
  delay(100); // let control stabilise
  currentZeroCal(); // calibrate zero current
  Serial.print("@");
#ifdef WIFI
  // remote command handling - Telnet, UDP, SCPI
  //Serial.println("Starting WiFi");
  //enableLoopWDT();
  if(myID.autoConnect)
  {
    wifiBegin();
    setupTelnet();
    //setup_http();     
    webServerStart();  
    UDPstart();// Serial.printf("UDP start %s\n",(UDPstart())?"OK":"BAD");
  }
  Serial.print(">");
#endif
  SCPI_setup();

  redrawScreen();
  //printDaughterCal();
  //printHalCal();
  getESPviReadings();

  //esp_task_wdt_init(10, true); // change the watchdog to 10 seconds
  //esp_task_wdt_add(NULL);
 //Serial.printf("Task subscribed to WDT %s\n", (esp_task_wdt_status(NULL) == ESP_OK)? "OK" : "BAD");
 //Serial.printf("fmap %3.2f\n", fmap(5, 0.0, 10.0, 0, 20));
  Serial.println("******** Done setup *******");
  //kelvinTest();
  Serial.println("SCPI Command?");
  delay(50);  
  lTimer =  mTimer = fTimer = vfTimer = vTimer = cTimer = tTimer = millis();
  enableLoopWDT();  // should already be done automatically
}
int count = 0;

#include "myLTouchProcess.h"

// ADS finished conversion 
// - resumes controlTask()
// - watchdog in loop()
void IRAM_ATTR ads_ISR(){  
  BaseType_t xYield;
  //portENTER_CRITICAL_ISR(&mux);
  adsReady = true;
  adsLastInt = millis();
  adsISRcount = adsISRcount + 1;
  //portEXIT_CRITICAL_ISR(&mux);
  xYield = xTaskResumeFromISR(controlTaskHandle);
  portYIELD_FROM_ISR(xYield);
}

uint16_t potval = 0;
bool updateZero;
short UDPcnt;
long lastADS = 0;
bool dp;


// all I2C processing called from here to avoid conflicts.


long ADStLast;
long screenHoldStart = 0;
void loop() /**************** LOOP ***************************/
{ 


 // if(!(esp_task_wdt_reset() == ESP_OK))    Serial.println("WDT not fed.");;
 //  fineTime = micros();
   /* very fast stuff */    
#ifndef ALTENCODER 
   enc.loop();
#endif
   // tUsec = micros();
#ifdef C_DEBUG    // slow down control for debug
 if(millis() - cdTimer > PROCESS_EVERY_CDEBUG)
 { 
   cdTimer = millis();
#endif
  // control was here
#ifdef C_DEBUG // slow down control for debug (see myControl.h)
 }
#endif   
 if(millis() > vfTimer + PROCESS_EVERY_VF)
    {   
      // just rise and fall (slew) setting 
      vfTimer = millis(); 
      // update dynamic settings, let control() take care of output management
      if(pSet.modeB == MODE_ST) // mode resets to NOR once cycle(s) are completed???
         dynSet = stepCalc();
      else
        if(pSet.modeB != MODE_BAT)
           dynSet = pSet; // values may have changed - BAT test takes care of this explicitly
    }    
     MY_FEED_LOOP_WDT(); yield(); // let ESP32 background tasks run
     
    if(millis() > fTimer + PROCESS_EVERY_F)
    {   
      fTimer = millis();  
      if(pSet.modeB == MODE_BAT) // mode resets to NOR once cycle is completed
      {         
         batTest();
      }
     // Serial.print("F"); delay(1);
      // but.loop(); // encoder switch not used
      butL.loop(); // L & R switches
      butR.loop();
      processOnOffSw();
    }
    MY_FEED_LOOP_WDT();
    yield(); 

    long adsL = adsLastInt;   
   
    if(millis() - cTimer > PROCESS_EVERY_CTRL)
    { 
      cTimer = millis();
      
     // detect lost adsReady interrupt (should occur every 1.2mS)   
      if((millis() - adsLastInt) > ADS_WATCHDOG) // && !holdScreen???
      {
#ifndef NO_ERRORS
         Serial.printf("*** Lost ADS interrupt, restart after ISR %i S, last restart was %3.2fmS {ISR count %i). ", millis() - adsLastInt, (millis() - ADStLast)/1000.0, adsISRcount);
#endif
         // kick the ADS conversion process
         portENTER_CRITICAL_ISR(&mux); // avoid interrupts during processing
           adsReady = false;      
           vTaskResume(controlTaskHandle);     
         portEXIT_CRITICAL_ISR(&mux);
         ADStLast = millis();
#ifndef NO_ERRORS
         Serial.println("Restarted");
#endif
      }
#ifdef WIFI
      process_SCPI(); // do this faster than we send out messages - or deadly embrace can occur.
#endif
    // logging
    if(_outOn && (pSet.modeB != MODE_BAT)) // Bat test has its own logging cycles
    {
      addLog(false); // log after mode and timing analysis; don't force log entry 
    }
   }
   MY_FEED_LOOP_WDT();
   yield(); 
       
   if(millis() > mTimer + PROCESS_EVERY_M)
   {  
    //Serial.print("-");
   // if(_outOn && meas.ADSvoltsAvg < 19.3)printADSavg();
    mTimer = millis();    
    //if (meas.ADSamps < RESPMIN_I || ((dynSet.mode != MODE_CC) &&  meas.ESPvolts < RESPMIN_V) ) Serial.print(" ESPLO ");

    lastADS = adSProcessCount;   
    
     // control inputs: encoder, buttons and touch    
     _scrTouched = processTouchSwEnc(); 

     if (dirtyScreen && !holdScreen)
       redrawScreen();

     if(changedVal_remote && !holdScreen)  // update all settings, as something has changed remotely
     {
     // Serial.print('#');
       drawSettings(-1, 0, true); // redraw all settings, nothing selected
       changedVal_remote = false; 
     }
     if(!_outOn)
     {
       rReading = 0.0;
       pReading = 0.0;
     }
     else
     {  
       rReading = abs((iReading < SMALL_DIFF) ? 0.0 : vReading / iReading);
       pReading = abs(vReading * iReading);
     }
     /*
     if(pSet.logTime > 0 && pSet.logTime < MINLOG)
     {
       pSet.logTime = MINLOG; 
       valChanged(VAL_CHGD);
     }     
     */
     if(!holdScreen)
        drawReadings(); // only one per cycle
     count++;
  }
  MY_FEED_LOOP_WDT();
  yield(); 
  
  
  // lower priority  - screen redraw
  if(millis() > lTimer + PROCESS_EVERY_L)
  {
    lTimer = millis();     
    //Serial.printf("ADSV %2.3f\n", meas.ADSvolts);
    
    if(highButton >= 0 && highButton < NUMBUTS) // ensure highlighted set digit is always visible
    {
      //int sv =  but[highButton].sv;  
      butDigit = constrainButDig(butDigit, highButton); 
      //Serial.printf("BD[%i] = %i [%i..%i]\n", highButton, butDigit, (1 - setVals[sv].post),(setVals[sv].post -1) );
    } 
    
    // non-blocking screen error  
    if(newScrError || holdScreen) 
    {
      if(newScrError) 
      {
        screenHoldStart = millis();
        holdScreen = true;
        screenError(scrE.message, scrE.bgcol, scrE.onTime, scrE.logo);   // , blocks initially for 0 seconds
        newScrError = false;
        //Serial.printf("Holding screen %iS\n", scrE.onTime);
      } 
      if(scrE.onTime >= 0)
      {
        if((millis() -  screenHoldStart)/1000 > scrE.onTime)
          holdScreen = false;
          dirtyScreen = true;
      }
      else
      {
        if(_scrTouched)
          holdScreen = false;
          dirtyScreen = true;
      }
    }
    meas.ESPtemp = readESP_T(); // update temp 
    if( meas.ESPtemp > TMAXOP) // slow response
    {
      onOffKill(0, false);
      errorKill(true, true, meas.ESPtemp, "Maximum temperature exceeded", true);      
    }
    //setFan(60);
    fanControl();
   //Serial.printf("Fan %i pwm [%2.1f C]\n", fanControl(), meas.ESPtemp);

#ifdef xxxC_DEBUG // slow down control for debug
    _DACis = control(ADS_CONTROL);
#endif
    startUp = false; // startUp concluded first time this is called
    if(!holdScreen)
    {
      drawIndicators(currentMenu);
      drawLegends(currentMenu);
    }
    myBlink = !myBlink;  
    if(!_outOn && updateZero) // re-calibrate zero current offset
    {   
      currentZeroCal(); 
      updateZero = false;
    }
  } 
  MY_FEED_LOOP_WDT();
  yield(); 

  
  if(millis() > vTimer + PROCESS_EVERY_VL)
  {
    // Serial.printf("\nLoop %2.2f mS; ADS %2.2f mS\n", (float)(millis() - vTimer)/lcount, (float)(millis() - vTimer)/adsCount);
   // Serial.printf("\nControl loops %li (%li)\n", controlLoops, controlLoops - lastLoops);
    //lastLoops = controlLoops;
    vTimer = millis();          
    adsCount = lcount = 0;
#ifdef WIFI
     //UDPcnt = SCPIgroupHeartbeat();
#endif
    saveSettings();
     //saveEE();  // set flag if Profile value changed. Only saves after SAVE_EE_AFTER loops
     updateZero = true; // Current zero offset calibration at next "L" cycle
     //Serial.printf("Active SCPI streams %i, LLR %5.2f\n",UDPcnt, localLimitRatio);
     //Serial.printf("Limit:  %i [%i], Track: %i [%i], Output: %i\n", pContA.limitInd, pSet.limitOn, pContA.trackInd, pSet.trackOn, pSet._outOn);
    //Serial.printf("Setpoint Nom: %5.2F / %5.2F, act: %5.2F\n", pSet.voltage, pContA.vSetpointR, pContA.vSetpointX);
    // Serial.printf("Amps %3.3f, DAC %i, ampsToDAC %i\n", meas.ADSamps, _lastDAC, ampsToDAC(meas.ADSamps));
     //Serial.printf("saveEE ind %i\n",needToSaveEE);
    
    //printDynSet();
   // printADC(true);
      //Serial.printf("Free heap %i\n",ESP.getFreeHeap());
  // printHalCal();
  //    printDaughterCal();
    //printSTEP();
    //Serial.printf("Heartbeat: Output %s\n", (_outOn) ? "On" : "Off");
    //Serial.printf("Output %s\n", (_outOn) ? "On" : "Off");
   //Serial.printf("pMaxOp %2.2f, dynSet.current %2.2f, meas.ADSvolts %3.2f, calc set pwr %3.2f, calc Max cur %2.2f\n", pMaxOp, dynSet.current, meas.ADSvolts, dynSet.current * meas.ADSvolts, pMaxOp / meas.ADSvolts);
  // Serial.printf("Volts: ADS count = %i, %2.3fV\n", ADCcount.ADSv, meas.ADSvolts);
   //Serial.printf("DAC: %i\n", _lastDAC);
  //Serial.printf("ESPamps %2.2f [%i], ADSamps %2.2f, ", meas.ESPamps, ADCcount.ESPa, meas.ADSamps );
  // Serial.printf("Volts: ADS %2.3fV[%2.3fV](%i)\n",  meas.ADSvolts, meas.ADSvoltsAvg, ADCcount.ADSv);
  // printICal();
  // printVCal();
   //  Serial.printf("pSet.logTime %i\n", pSet.logTime);
  // Serial.printf("dynSet.current %2.3f\n", dynSet.current);
   // Serial.printf("Fan %i - done\n",readFan());
  //  Serial.printf("Control time = %i\n", controlTime/loops); loops = 0; controlTime = 0;
 //   float ctRatio = (1000 * controlTime) / (micros() - controlStart);
  //  Serial.printf("control loop time %5.1f%%\n", ctRatio/10);
  //Serial.printf("BTS %i \n",batTestState);
  //printADSavg();
  }
  lcount++;
  MY_FEED_LOOP_WDT();
  yield(); 
  
   /*
  loopTimetest(); // fineTime = micros(); needs to be uncommented at the top of loop()
 */
}

// keep the digit being changed for the selected setting within bounds.
int constrainButDig(int butDig, int hBut)
{
  int svx = but[hBut].sv; 
  int post = setVals[svx].post;
  int pre = setVals[svx].pre;
  // assume  post and pre are not *both* zero
  if(post == 0) // integer
    butDig = constrain(butDig, 0, pre - 1);
  else
    butDig = constrain(butDig, -post, pre - 1);
  if(pre == 0) // no XXX. part
    butDig = constrain(butDig, -post, -1);
  return butDig;
}
/*
void zeroBuckets(void){
  for (int  i = 0; i < NBUCKETS; i++)
    timeBucket[i] = 0;
}
void printBuckets(void){
  for (int  i = 0; i < NBUCKETS; i++)
  {
    Serial.printf(", %i",timeBucket[i] );
    if(i % 10 == 0)
    Serial.printf("\n %2i: ", i);
  }
}
*/
/*
void A2Dtest(void){
  int vall;
  for (float  i = 0; i < RDACHI_I; )
  {
    vall = ampsToDAC(i);
    //Serial.printf("DAC: %2.3f %i\n", i, vall);
    i = i * 1.2 + 0.01; 
  }
}
*/
// test routine
/*
void cvtADSReadings(void)
{
  // convert ADS counts to volts/amps
  //Serial.println("get ADS read");
  meas.ADSvolts = ADStoV(ADCcount.ADSv);
  meas.ADSamps  = ADStoA(ADCcount.ADSa);
  pReading = meas.ADSvolts * meas.ADSamps;
  if(meas.ADSamps > MEDIUM_DIFF)
     rReading = meas.ADSvolts / meas.ADSamps;
}
*/
void printDynSet(void)
{
  Serial.printf("dynSet: %3.2fV  %3.2fA, ", dynSet.voltage, dynSet.current);
  Serial.printf("mode = %i, modeB = %i\n", dynSet.mode, dynSet.modeB);
}
void printADC(bool isLong)
{ 
  getESPviReadings();// OK to update these
  // don't read ADS directly, interrupt driven conversion
  if(isLong)
  {
   
    Serial.printf("ADC: %i Mmeas [ESP]: ", adSProcessCount);
    Serial.printf("A: %2.3f %i [%2.3f %i]",   meas.ADSamps, ADCcount.ADSa, meas.ESPamps, ADCcount.ESPa); 
    Serial.printf(", V: %2.3f %i [%2.3f %i]", meas.ADSvolts, ADCcount.ADSv, meas.ESPvolts, ADCcount.ESPv);      
    Serial.printf(", T: [%2.3f %i]", readESP_T(), ADCcount.ESPt);     
    Serial.printf(", DAC: %i, OutOn %i\n", _DACis, _outOn);  
  } else
  {
    Serial.printf("ADC: %i Meas [ESP]: ", adSProcessCount);
    Serial.printf("A: %2.3f [%2.3f]",   meas.ADSamps, meas.ESPamps); 
    Serial.printf(", V: %2.3f [%2.3f]", meas.ADSvolts, meas.ESPvolts);      
    Serial.printf(", T: [%2.3f]\n", readESP_T());  
  }
}
void printDaughterCal(void)
{
  Serial.printf("dPresent %i [%i], iMaxOp %2.1f\n", myID.daughter_present, (digitalRead(DPRESENT) == LOW), iMaxOp );
  Serial.printf("halCal[ADS_I].maxVal %2.1f, maxErr %2.1f\n", halCal[ADS_I].maxVal, halCal[ADS_I].maxErr);
  Serial.printf("halCal[ESP_I].maxVal %2.1f, maxErr %2.1f\n", halCal[ESP_I].maxVal, halCal[ESP_I].maxErr);
    Serial.printf("halCal[ADS_V].maxVal %2.1f, maxErr %2.1f\n", halCal[ADS_V].maxVal, halCal[ADS_V].maxErr);
   Serial.printf("halCal[ESP_V].maxVal %2.1f, maxErr %2.1f\n", halCal[ESP_V].maxVal, halCal[ESP_V].maxErr);
  Serial.printf("VMAXOP %3.2f, IMAXOP %3.2f[%3.2f], PMAXOP %3.2f{%3.2f]\n",VMAXOP, IMAXOP, iMaxOp, PMAXOP, pMaxOp);
}
void printVCal(void)
{
  Serial.printf("halCal[ADS_V] %2.1f .. %2.1f [%i  .. %i], maxErr %2.1f\n", halCal[ADS_V].lowCalVal, halCal[ADS_V].hiCalVal, halCal[ADS_V].lowCalCount, halCal[ADS_V].hiCalCount, halCal[ADS_V].maxErr);
  Serial.printf("halCal[ESP_V] %2.1f .. %2.1f [%i  .. %i], maxErr %2.1f\n", halCal[ESP_V].lowCalVal, halCal[ESP_V].hiCalVal, halCal[ESP_V].lowCalCount, halCal[ESP_V].hiCalCount, halCal[ESP_V].maxErr);
}
void printICal(void)
{
  Serial.printf("halCal[ADS_I] %2.2f %2.2f %2.2f [%i  %i %i], maxErr %2.1f\n", halCal[ADS_I].lowCalVal, halCal[ADS_I].midCalVal, halCal[ADS_I].hiCalVal, halCal[ADS_I].lowCalCount, halCal[ADS_I].midCalCount, halCal[ADS_I].hiCalCount, halCal[ADS_I].maxErr);
  Serial.printf("halCal[ESP_I] %2.2f %2.2f %2.2f [%i  %i %i], maxErr %2.1f\n", halCal[ESP_I].lowCalVal, halCal[ESP_I].midCalVal, halCal[ESP_I].hiCalVal, halCal[ESP_I].lowCalCount, halCal[ESP_I].midCalCount, halCal[ESP_I].hiCalCount, halCal[ESP_I].maxErr);
   Serial.printf("halCal[DAC] %2.2f %2.2f %2.2f [%i  %i %i], maxErr %2.1f\n", halCal[DAC].lowCalVal, halCal[DAC].midCalVal, halCal[DAC].hiCalVal, halCal[DAC].lowCalCount, halCal[DAC].midCalCount, halCal[DAC].hiCalCount, halCal[DAC].maxErr);
}
void printADSavg(void)
{
#ifndef NO_ERRORS
    Serial.printf("ADsAvg %3.3f [%3.3f]: ", meas.ADSvoltsAvg, meas.ADSvolts);
    for(int i = 0; i < NUM_AVG_VOLTS; i++)  
        Serial.printf("%2.3f, ",batVolts[i]);
    Serial.println();
#endif
}
void kelvinTest()
{
  digitalWrite(KELPIN, LOW); // should already be in MAIN mode
    float mVolts, kVolts;
    vTaskDelay(500); 
    mVolts = meas.ADSvoltsAvg;
    printADSavg();
    
    digitalWrite(KELPIN, HIGH); //
    vTaskDelay(500); // additional time for relay
    printADSavg();
    kVolts = meas.ADSvoltsAvg;
    
    Serial.printf("KT: vM %2.3f, vK %2.3f\n", mVolts, kVolts);
    digitalWrite(KELPIN, LOW);
}

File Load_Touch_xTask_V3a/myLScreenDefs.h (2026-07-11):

/* Screen and touch defs 
*/
#ifndef  MYSCREENDEFS_H
#define  MYSCREENDEFS_H

#include "SPI.h"
#include "Adafruit_GFX.h"

#include <XPT2046_Touchscreen.h>

#ifdef ILI9341 
#define sx(x)	((short)(x))	// no scaling
#define sy(x)	((short)(x))	// no scaling
#include "Adafruit_ILI9341.h"
Adafruit_ILI9341 tft = Adafruit_ILI9341(LTFT_CS, LTFT_DC);
//Adafruit_ILI9341 tft = Adafruit_ILI9341(LTFT_CS, LTFT_DC, LTFT_RST);
//Adafruit_ILI9341 tft = Adafruit_ILI9341(LTFT_CS, LTFT_DC, LTFT_MOSI, LTFT_CLK, LTFT_RST, LTFT_MISO);
#endif

#ifdef ILI9488
// see also  myInst.h
#define sx(x)	((short)(1.5 * (x)))	  // scale by 480/320 for bigger display
#define sy(x)	((short)(1.333 * (x))) // 320/240
Arduino_DataBus *bus = new Arduino_ESP32SPI(LTFT_DC, LTFT_CS, LTFT_CLK /* SCK */, LTFT_MOSI /* MOSI */, -1 /* MISO */, VSPI /* spi_num */);
Arduino_ILI9488_18bit tft =  Arduino_ILI9488_18bit(bus, LTFT_RST, 0, false /* IPS */);
#endif

#ifdef ILI9488
	//#include "myFonts/DejaVu_Sans_Mono_Bold_16.h"
	#include "myFonts/DejaVu_Sans_Mono_Bold_18.h"
	#include "myFonts/DejaVu_Sans_Mono_Bold_22.h"
	//#include "myFonts/DejaVu_Sans_Mono_Bold_24.h"
	//#include "myFonts/DejaVu_Sans_Mono_Bold_26.h"
	#include "myFonts/DejaVu_Sans_Mono_Bold_32.h"
	#include "myFonts/DejaVu_Sans_Mono_Bold_42.h"
	
	#define FONT0 DejaVu_Sans_Mono_Bold_18  // smallest
	#define FONT1 DejaVu_Sans_Mono_Bold_22  // small
	//#define FONT2 DejaVu_Sans_Mono_Bold_22  // larger
	//#define FONT2 DejaVu_Sans_Mono_Bold_24  // larger
	#define FONT2 DejaVu_Sans_Mono_Bold_32  // larger
	//#define FONT2 DejaVu_Sans_Mono_Bold_28  // larger
	#define FONT3 DejaVu_Sans_Mono_Bold_42        // biggest
#else // ILI9341
	#include "myFonts/DejaVu_Sans_Mono_Bold_16.h"
	#include "myFonts/DejaVu_Sans_Mono_Bold_18.h"
	//#include "myFonts/DejaVu_Sans_Mono_Bold_22.h"
	#include "myFonts/DejaVu_Sans_Mono_Bold_24.h"
	//#include "myFonts/DejaVu_Sans_Mono_Bold_26.h"
	#include "myFonts/DejaVu_Sans_Mono_Bold_28.h"
	//	#include "myFonts/DejaVu_Sans_Mono_Bold_32.h"
	//#include "myFonts/DejaVu_Sans_Mono_Bold_38.h"
	
	#define FONT0 DejaVu_Sans_Mono_Bold_16  // smallest
	#define FONT1 DejaVu_Sans_Mono_Bold_18  // small
	//#define FONT2 DejaVu_Sans_Mono_Bold_22  // larger
	#define FONT2 DejaVu_Sans_Mono_Bold_24  // larger
	//#define FONT2 DejaVu_Sans_Mono_Bold_26  // larger
	#define FONT3 DejaVu_Sans_Mono_Bold_28  // larger
	//#define FONT3 DejaVu_Sans_Mono_Bold_32  // biggest
	//#define FONT3 DejaVu_Sans_Mono_Bold_38        // biggest
#endif

#define NUMFONTS 4
const GFXfont *myFonts[NUMFONTS] = {&FONT0, &FONT1, &FONT2, &FONT3};

#define MY_DARKGREEN 0x034E0
#define MY_RED 0xF800
#define MY_WHITE 0xFFFF
#define MY_YELLOW 0xFFE0
#define MY_GREEN RGB565_RP(0,36,0)
#define RGB565_RP(R, G, B) (((R)<<11)|((G)<<5)|(B))  
#define LIGHTYELLOW RGB565_RP(31,63,0)
#define YELLOW_VL RGB565_RP(31,63,10)
#define CYAN_L RGB565_RP(15,45,31)
#define CYAN_VL RGB565_RP(21,63,31)
#define CYAN_M RGB565_RP(8,32,24)
#define GREEN_L RGB565_RP(5,63,5)
#define CYAN_M RGB565_RP(8,32,24)
#define PINK_M RGB565_RP(31,28,31)
#define MY_ORANGE RGB565_RP(31,31,0)	// R + G/2
// special colours
#define VOLT_COL LIGHTYELLOW
#define AMP_COL GREEN_L
#define WATT_COL PINK_M
#define RES_COL CYAN_L
#define TEMP_COL 0x0F9CB
// screen background
#define BGCOL 0 
#define BGHIGH RGB565_RP(5,11,4)  
#define MIDBG RGB565_RP(5,11,4) 
// value text
#define TEXTCOL  MY_YELLOW
#define HIGHLIGHTCOL MY_WHITE
//menu button items
#define BTEXTCOL RGB565_RP(20,36,20) //light grey
#define BHIGHCOL 0xffff  //LIGHTYELLOW // MY_YELLOW // ILI9341_BLACK 

// menu button backgrounds
#define BBORDHIGH BHIGHCOL
#define BBORD BGCOL
#define BBGHIGH RGB565_RP(0,14,28) // MED blue
#define BBXHIGH RGB565_RP(0,0,20)  // DK blue
#define BBSHIGH RGB565_RP(20,10,0) // MED ORANGE
// mode buttons
#define BONCOL MY_WHITE
#define BBMHIGH RGB565_RP(0,45,0) // bright green
#define BBMXHIGH RGB565_RP(3,20,0) // med green
// cal buttons
#define BBRHIGH RGB565_RP(31,0,0)
#define BBRXHIGH RGB565_RP(15,0,0)

// error screen backgrounds
#define ERR_BG_A MY_DARKGREEN
#define ERR_BG_B MY_RED

// indicator BG colours
#define ITRIG MY_RED 			// Action triggered
#define IENABLE	MY_DARKGREEN	// Function enabled
#define IND_ONC MY_GREEN
#define IND_ONLC GREEN_L		// FAN medium
#define IND_OFFC MY_RED			// FAN High
#define IND_GO_COL RGB565_RP(0,20,32)
// screen calibration 
struct screenCals {
  int16_t thmin; // tft.pixel (0,0)
  int16_t tvmin;
  int16_t thmax;// tft.pixel (HMAX,VMAX)
  int16_t tvmax;
  uint8_t tsRot;	// screen rotation - as some touch screens are rotated 180%
  uint8_t scrRot;  // screen rotation - as some touch screens are rotated 180%
} ;
screenCals sc = {400, 300, 3900, 3700, TOUCHROT, SCREENROT}; // useful starting values, overwritten by screen cal and EEPROM restore.

// touch units to screen pixel conversions
int16_t pxh (int16_t px){ 
  int x = ((px-sc.thmin)*HMAX)/(sc.thmax-sc.thmin);
  if (x < 0) return 0;
  if (x > HMAX) return HMAX;
  return x;
}
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

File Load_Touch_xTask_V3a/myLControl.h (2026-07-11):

#ifndef MYLCONTROL_H
#define MYLCONTROL_H
/*
 Control the DAC
 Exclusive: I2C control from these routines called by ControlTask()
 Watch out for stack size if writing to Serial from these routines (overflow may restart ESP). 
*/
int dxxx =0;
void IRAM_ATTR ads_ISR();
void onOff(int8_t channel, bool status);
void onOffKill(int8_t channel, bool status);
short SCPIsendGrpMessage(uint8_t tgrp, char *buf);
uint8_t setMode(uint8_t aMode);
uint8_t setModeB(uint8_t bMode);
int limitMe(float curVal, float setPoint, float readV, float readI, int modeX);
void errorKill(bool shutOff, bool DACzero, float reading, const char errMsg[], bool nonBlock);
int modeCalc(float readV, float readI, uint8_t c_speed, bool guessFirst, bool printMe);
bool daughterSense(void);
bool getESPviReadings(void);
bool addLog(bool mustLog);
void addLogItem(float setting, const char mode[], const char func[], bool tsec);
void addBatLogItem(float ocvolts, float ccvolts, float amps, float esr, float mah, float mwh);
void restartLog(void);
void restartBatLog(void);
void  averageVolts(void);
void printADSavg(void);
void printLog();
void printBatLog();
//int dacRead(void);

bool changedLocal = true; // last value changed was local (or remote)
//bool shutDown = false;
bool firstGuess = true; // deal with non-linear cases where first guess is outside the C_VARCOARSE window, also at switch on
float openV;

// coarse and fine control for main output with limiting and tracking
char estop[] = ":TRAC:ESTO";
int cVal = 0;
// must be non-blocking

settings t; // used by BAT and STEP modes. Needs to be persistent, as most times routines just exit.

/* ==== Battery Test ====
 * set and hold appropriate discharge setting
 * every BAT_MEASURE_INTERVAL (and at start) disconnect for several seconds and measure open circuit voltage.
 *   calculate ESR and display - need to stop normal resistance calculation
 * monitor for final voltage, when reached, measure ESR again.
 * go to NOR/Off mode.
 * display results - errorI: mod to hold until screen touched.
 */
long tLastBatUpdate, tBatStart, tSinceLastBatUpdate;
float batAH, batMAH, batWH, batMWH; // amp hrs and watt hours, running total
float fValue;
//#define BAT_MEASURE_INTERVAL 20 // seconds between battery measurements
#define BAT_WAIT_MEASURE_TIME 1000 // milliSeconds of zero current for battery recovery before measuring OC voltage
float batOCvolts = 999, batCCvolts = 999, batCurrent = 999;
bool batUpdateMode;
float esr;
bool preStart = false;
#define MS_TO_HRS 3600000 // (3600 * 1000)

float batVoltsFiltered;

#define BT_START      0
#define BT_FIRST      1
#define BT_RUNNING    2
#define BT_WAIT_MEAS  3
#define BT_DONE       4
uint8_t batTestState = BT_DONE;

// returns true while battery test is active
bool batTest(void) {
  int i;
  int bmi = pSet.logTime * 1000;
  // 2 step start: 
  // step 1: prestart - turn On and set current to zero
  if (_curState == BMODE_SEL) // start   
  { 
    tBatStart = tLastBatUpdate = millis();
    Serial.printf("Battery test - start %i\n", tLastBatUpdate);    
    onOff(0, true); // resets log
    dynSet.current = 0.0;   // turn discharge current to zero to measure OCV
    dynSet.power = 0.0;     // could be CP or CR mode
    dynSet.resistance = 9999.0;
    preStart = true;  
    _batStop = false;
    _curState = BMODE_RUN;  
    batTestState =  BT_FIRST;
    //restartBatLog();
    return true;
  }

  tSinceLastBatUpdate = (millis() - tLastBatUpdate);
    
  // prep step 2: after startup + measurement delay, log the initial values; then begin the test
  if (batTestState == BT_FIRST && tSinceLastBatUpdate > BAT_WAIT_MEASURE_TIME) 
  {       
    batOCvolts = meas.ADSvoltsAvg;
   //Serial.printf("Bat start 2:  CC %2.3fV, dacVal %i, set %2.3fA,\n", batOCvolts, _DACis, dynSet.current);
    //batCurrent = meas.ADSamps;
    //Serial.printf("Bat: 2 %2.3fV %2.3fA @ %i\n", batOCvolts, batCurrent, millis());    
    addLogItem(pSet.voltage,"TERM_V", "BAT", true); 
    if (pSet.mode == MODE_CC)   
      addLogItem(pSet.current,"DIS_A", "BAT", true);  
    if (pSet.mode == MODE_CP)
      addLogItem(pSet.power,"DIS_P", "BAT", true);
    if (pSet.mode == MODE_CR)
      addLogItem(pSet.resistance,"DIS_R", "BAT", true);
      
    restartBatLog();
    addBatLogItem(batOCvolts, 0.00, pSet.current, 0.0, 0.0, 0.0);   // assumes CC mode
   
    //batUpdateMode = false;
    batAH = 0.0;
    batWH = 0.0;
    
    dynSet = pSet; // turn discharge on after measuring OCV
    //preStart = false; // reset for next time.
    tLastBatUpdate = millis();
    batTestState = BT_RUNNING;
    return true;
  }

  // If we get to this point startup is complete and testing is active
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

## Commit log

2023-03-01 Change current trigger value
2023-03-01 ESP ADS current difference
    Fix error in calculating differences between ADS and ESP current difference calculation in controlTask()
    [Load_Touch_xTask2a.ino]
2023-03-01 Comment out diagnostic print
2023-03-01 improve ESP current calculation
2023-03-01 Update ESP current parameters
2026-06-09 Fix ESP32 Arduino core v3.x compatibility for Linux builds
    - Fix case-sensitive filename mismatches for Linux compatibility:
    myLads1115bits.h -> myLADS1115bits.h
    myLSPIFFSprofile.h -> myLSPIFFSProfile.h
    myLWiFi.h -> myLWifi.h
    platyimg2.h -> platyImg2.h
    - Add missing myI2Cscan.h copied from source_v2
    - Fix AsyncWebParameter const correctness in myLwebserverSPIFFS.h
    - Replace deprecated ledcSetup/ledcAttachPin with ledcAttach in myLControl.h and main sketch
    - Fix esp_task_wdt_init() call to use esp_task_wdt_config_t struct (core v3.x API)
    - Sanitise wifiSecrets.h to remove hardcoded credentials
    [Load_Touch_xTask_V3a.ino, myLADS1115bits.h, myLControl.h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]
2026-07-06 Migrate filesystem from SPIFFS to LittleFS
    - SPIFFS.begin() -> LittleFS.begin() in myLProfile.h, mount function
    renamed SPIFFSstart() -> LittleFSstart()
    - profile.json read/write/listDir calls in myLSPIFFSProfile.h switched
    to LittleFS
    - Web server static file routes (CSS, JS, favicon, PNGs) in
    myLwebserverSPIFFS.h switched to LittleFS
    - Added explicit #include "LittleFS.h" to myLProfile.h so it no
    longer depends on include order elsewhere
    - Verified: compiles clean, LittleFS image uploaded via
    arduino-littlefs-upload, web UI loads correctly on device
    [Load_Touch_xTask_V3a.ino, myLProfile.h, myLwebserverSPIFFS.h]
2026-07-07 Add connected IP display to boot sequence; confirm mDNS
    - mDNS (ESPmDNS) confirmed already present and correctly wired in
    both connection paths (LAN and softAP fallback) - no fix needed
    - LAN connect branch: reordered IP/hostname setup to occur before the
    'Connected to local LAN' screen message, so IP is available to
    display; added 'IP = %s' to the message; reduced display duration
    from 5s to 2s
    - AP fallback branch: added a new screenError() call showing SSID
    and IP address, styled consistently with the LAN branch (2s,
    ERR_BG_A)
    Verified: compiles clean, flashes and boots correctly, IP address
    displays as expected on both connection paths
2026-07-09 Add Kelvin mod gerber files
    [load mini 7 tht-CuBottom.gbr, load mini 7 tht-CuTop.gbr, load mini 7 tht-EdgeCuts.gbr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]
2026-07-09 Add board image
2026-07-09 Board image
2026-07-14 fix fan issue
